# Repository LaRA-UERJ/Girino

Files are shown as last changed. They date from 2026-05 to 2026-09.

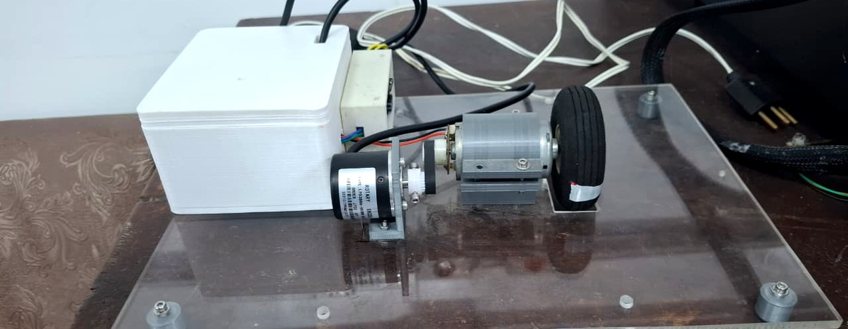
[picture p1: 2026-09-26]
docs/infografico/foto-bancada.jpg

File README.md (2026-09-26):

# Girino





Plataforma didática do **LaRA** (Laboratório de Robótica e Automação) para ensino de controle de motores DC. Integra microcontrolador, driver MOSFET e encoder em uma bancada compacta para introdução prática à leitura de sensores, modulação PWM e controle em malha fechada.

## Status do Projeto

| Componente | Status |
|---|---|
| Estrutura do repositório | ✅ Criada |
| Firmware (ESP8266) | 🚧 Em desenvolvimento |
| Hardware (PCB - KiCad) | 📋 Planejado |
| Mecânico (Caixa 3D) | 📋 Planejado |
| Documentação | 🚧 Em desenvolvimento |
| Exemplos didáticos | 📋 Planejado |

## Funcionalidades

- Controle PWM de motor DC via ESP8266
- Leitura de encoder incremental (LPD3806-600BM — 600 PPR)
- Atualização de firmware via OTA (Wi-Fi)
- Interface web para controle e monitoramento
- Controle PID de velocidade/posição
- Design compacto para bancada de laboratório

## Componentes de Hardware

| Componente | Descrição |
|---|---|
| ESP8266 WROOM | Microcontrolador com Wi-Fi |
| LPD3806-600BM | Encoder incremental, 600 pulsos/revolução |
| Módulo driver motor | Driver genérico MOSFET para motor DC |
| Módulo conversão tensão | Regulador de tensão para alimentação do circuito |

## Estrutura do Repositório

```
Girino/
├── firmware/          # Firmware ESP8266 (PlatformIO)
├── hardware/          # PCB designs (KiCad), gerbers, BOM
├── mechanical/        # Peças 3D (FreeCAD, STL, STEP)
├── docs/              # Documentação completa
├── examples/          # Exemplos didáticos passo a passo
├── gallery/           # Fotos e renders do projeto
└── .github/           # Templates e CI/CD
```

## Início Rápido

Veja o guia completo em [`docs/getting-started.md`](docs/getting-started.md).

### Pré-requisitos

- [PlatformIO](https://platformio.org/) (extensão VSCode recomendada)
- USB cable para gravação inicial do ESP8266
- Componentes listados no BOM (ver [`hardware/bom/`](hardware/bom/))

### Compilar e Gravar

```bash
cd firmware
# Configurar WiFi — copiar template e editar
cp .env.example .env

# Compilar e gravar via USB
pio run -t upload

# Após gravação inicial, usar OTA para atualizações
pio run -t upload --upload-port girino.local
```

## Documentação

- [Guia de Início Rápido](docs/getting-started.md)
- [Montagem do Hardware](docs/hardware-assembly.md)
- [Guia do Firmware](docs/firmware-guide.md)
- [Atualização OTA](docs/ota-update-guide.md)

## Exemplos Didáticos

| # | Exemplo | Descrição |
|---|---|---|
| 01 | [Controle Básico de Motor](examples/01-basic-motor-control/) | PWM para controlar velocidade do motor |
| 02 | [Leitura de Encoder](examples/02-encoder-reading/) | Ler pulsos e calcular velocidade |
| 03 | [Controle PID](examples/03-pid-speed-control/) | Malha fechada de velocidade |
| 04 | [OTA Web Update](examples/04-ota-web-update/) | Atualizar firmware via Wi-Fi |
| 05 | [PID Web Test](examples/05-pid-web-test/) | Teste prático de PID com painel web e gráfico |

## Contribuindo

Contribuições são bem-vindas! Veja o guia em [`CONTRIBUTING.md`](CONTRIBUTING.md).

## Licenças

Este projeto utiliza **tripla licença**:

| Tipo | Licença | Arquivo |
|---|---|---|
| Firmware (código) | **GPL-3.0** | [`LICENSE`](LICENSE) |
| Hardware (PCB, esquemático) | **CERN-OHL-S-2.0** | [`LICENSE`](LICENSE) |
| Documentação e imagens | **CC-BY-SA-4.0** | [`LICENSE`](LICENSE) |

## Equipe

Desenvolvido no **LaRA — Laboratório de Robótica e Automação**.

## Agradecimentos

- Comunidade open-source ESP8266
- [ElegantOTA](https://github.com/ayushsharma82/ElegantOTA)
- [PlatformIO](https://platformio.org/)

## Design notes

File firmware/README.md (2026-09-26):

# Firmware — Girino

Firmware para ESP8266 WROOM com controle PWM de motor DC, leitura de encoder e OTA.

## Requisitos

- [PlatformIO](https://platformio.org/) (CLI ou extensão VSCode)
- Cabo USB para gravação inicial
- Python 3 (para PlatformIO)

## Configuração Inicial

O Girino opera como **Access Point**: ele cria a própria rede Wi-Fi
(chamada `GIRINO_AP` por padrão) e os alunos conectam direto pelo
celular/notebook, sem precisar de roteador nem internet.

```bash
# 1. Copiar template de credenciais
cp .env.example .env

# 2. (Opcional) Ajustar nome e senha da rede criada pelo ESP:
#    WIFI_SSID="GIRINO_AP"
#    WIFI_PASSWORD="girino123"     # mínimo 8 caracteres
#    OTA_PASSWORD="senha_para_ota"
nano .env
```

Após conectar na rede do ESP, acesse `http://192.168.4.1`.

## Compilar e Gravar

### Primeira gravação (via USB)

```bash
# Compilar
pio run

# Compilar e gravar o firmware
pio run -t upload

# Gravar o filesystem (interface web em data/) — OBRIGATÓRIO na
# primeira gravação e sempre que alterar arquivos de data/
pio run -t uploadfs

# Monitor serial (Ctrl+] para sair)
pio device monitor
```

> **Importante:** `pio run -t upload` grava apenas o firmware. A interface
> web (`data/index.html`, `style.css`, `app.js`, `chart.umd.min.js`) vive
> no LittleFS e é gravada com `pio run -t uploadfs`. Se a página abrir com
> "index.html nao encontrado no LittleFS", falta o `uploadfs`.

### Console serial (controle sem Wi-Fi)

O firmware tem um console de comandos na própria porta serial — útil para
bancada, testes rápidos e quando não se quer usar o navegador. Abra o
monitor (`pio device monitor`) e digite `help`:

| Comando | Descrição |
|---|---|
| `help` | lista os comandos |
| `status` | modo, RPM, ângulo, pulsos, heap, IP |
| `enc` | leitura do encoder agora |
| `motor <fwd\|rev\|stop> [0-100]` | comando manual (cancela controladores) |
| `pid <kp> <ki> <kd> <sp>` | configura o PID de velocidade (RPM) |
| `pid start` / `pid stop` | liga/desliga a malha de velocidade |
| `pos <kp> <ki> <kd> <graus>` | configura o PID de posição |
| `pos start` / `pos stop` / `pos zero` | controle de posição / zera origem |
| `autotune <amp> <bias> <n> <sp>` | inicia o relay feedback (velocidade) |
| `autotune pos <amp> <n> <graus>` | inicia o relay feedback (posição, ±amp) |
| `autotune cancel` | cancela o experimento |
| `tune` | mostra Ku/Tu e ganhos ZN/TL/CC do último auto-tune |

Durante qualquer controlador ativo, a telemetria sai a 2 Hz no serial
(`[PID] SP/RPM/Out`, `[Pos] Alvo/Ângulo/Out`, `[AutoTune] RPM/relay`), e o
encoder reporta 1 Hz (`[Encoder] pulsos/p-s/rpm/ângulo`).

### Auto-calibração do sentido (fiação)

No primeiro movimento após o boot, o firmware aplica um pulso curto de
teste e observa a contagem do encoder:

- Contagem positiva → fiação normal (`[Motor] Sentido OK`)
- Contagem negativa → fiação invertida detectada e **corrigida em
  software** (`[Motor] Fiacao invertida detectada`) — não é preciso
  trocar fios: "horário" (FORWARD) sempre aumenta o ângulo medido

As malhas de velocidade e auto-tune usam |RPM| e funcionam com qualquer
polaridade; a calibração garante também o controle de posição.

### Atualizações subsequentes (via OTA)

Conecte o computador na rede do próprio ESP (`GIRINO_AP`) ou use a
interface web em `http://192.168.4.1/update`.

```bash
# Via OTA (computador conectado ao GIRINO_AP)
pio run -t upload --upload-port 192.168.4.1
```

> OTA e `uploadfs` não são a mesma coisa: OTA grava o **firmware**;
> alterações na interface web (pasta `data/`) exigem `pio run -t uploadfs`
> via USB.

## Arquitetura do Firmware

```
src/
├── main.cpp            # Loop principal, WiFi, web server, API REST
├── motor_control.cpp   # Controle PWM do motor
├── encoder.cpp         # Leitura do encoder via interrupção
├── pid.cpp             # Controle PID em malha fechada (50 Hz)
├── pid_autotune.cpp    # Auto-tune via relay feedback (Åström-Hägglund)
└── pid_tuning_rules.cpp # Regras de sintonia Ziegler-Nichols, Tyreus-Luyben e Cohen-Coon

include/
├── pins.h              # Mapeamento de GPIOs (centralizado)
├── config.h            # Constantes e configurações
├── motor_control.h     # Interface do módulo motor
├── encoder.h           # Interface do módulo encoder
├── pid.h               # Interface do módulo PID
├── pid_autotune.h      # Interface do auto-tune
└── pid_tuning_rules.h  # Interface das regras de sintonia
```

## API REST

| Endpoint | Método | Descrição |
|---|---|---|
| `/` | GET | Interface web de controle |
| `/api/motor` | POST | Comando do motor (`direction`, `speed`) |
| `/api/encoder` | GET | Leitura atual do encoder (`pulses`, `rpm`, `angle`) |
| `/api/status` | GET | Status (versão, heap, uptime, IP, clientes do AP, modo) |
| `/api/pid/config` | GET/POST | Configura/consulta ganhos e setpoint do PID de velocidade |
| `/api/pid/start` | POST | Inicia controle de velocidade em malha fechada |
| `/api/pid/stop` | POST | Para o PID, volta a malha aberta |
| `/api/pid/autotune` | GET/POST | Inicia/consulta experimento relay feedback (`plant=speed\|position`) |
| `/api/pid/tuning` | GET | Planta identificada (`plant`), Ku, Tu e sugestões `zn`/`tl`/`cc` |
| `/api/pid/tuning/apply` | POST | Aplica regra de sintonia (`method=ZN|TL|CC`) |
| `/api/pid/response` | GET | Última resposta ao degrau (tempo, setpoint, medida, `unit`) |
| `/api/position/config` | GET/POST | Configura/consulta ganhos e alvo do PID de posição (`target` em graus) |
| `/api/position/start` | POST | Inicia controle de posição (`target` opcional em graus) |
| `/api/position/stop` | POST | Para o controle de posição |
| `/api/position/zero` | POST | Define a posição atual como 0° (origem) |
| `/update` | GET | Interface OTA (ElegantOTA) |

### Exemplos de uso da API

```bash
# Ligar motor em 50% sentido horário (malha aberta)
curl -X POST http://192.168.4.1/api/motor -d "direction=forward&speed=50"

# Parar motor
curl -X POST http://192.168.4.1/api/motor -d "direction=stop&speed=0"

# Ler encoder
curl http://192.168.4.1/api/encoder

# Status do sistema
curl http://192.168.4.1/api/status

# Configurar PID (setpoint em RPM)
curl -X POST http://192.168.4.1/api/pid/config -d "kp=2.0&ki=5.0&kd=0.1&setpoint=100"

# Iniciar malha fechada
curl -X POST http://192.168.4.1/api/pid/start

# Iniciar auto-tune de VELOCIDADE (relay ±10% em torno de bias 90%, 3 ciclos, setpoint 100 RPM)
# O bias (pedestal) precisa vencer a zona morta do motor — o PWM mínimo
# que faz o eixo girar (medido nesta bancada: ~80%). Use `bias` entre esse
# valor e 95%, e `relay_amplitude` de forma que bias ± amplitude fique
# dentro de 0-100%.
curl -X POST http://192.168.4.1/api/pid/autotune -d "plant=speed&relay_amplitude=10&bias=90&cycles=3&setpoint=100"

# Iniciar auto-tune de POSIÇÃO (relé simétrico ±90% em torno do alvo 90°)
# O relé alterna horário/anti-horário; a amplitude precisa ficar acima da
# zona morta (~60%) para ambos os estados moverem o motor. Os ganhos
# resultantes estão em %/° (malha de posição).
curl -X POST http://192.168.4.1/api/pid/autotune -d "plant=position&relay_amplitude=90&cycles=3&target=90"

# Consultar resultado do auto-tune (inclui "plant": onde os ganhos se aplicam)
curl http://192.168.4.1/api/pid/autotune

# Aplicar Tyreus-Luyben
curl -X POST http://192.168.4.1/api/pid/tuning/apply -d "method=TL"

# Baixar resposta ao degrau
curl http://192.168.4.1/api/pid/response

# --- Controle de posição (ângulo) ---

# Zerar a posição atual (define origem 0°)
curl -X POST http://192.168.4.1/api/position/zero

# Configurar PID de posição (alvo 90°)
curl -X POST http://192.168.4.1/api/position/config -d "kp=1.0&ki=0.2&kd=0.05&target=90"

# Iniciar controle de posição
curl -X POST http://192.168.4.1/api/position/start

# Parar controle de posição
curl -X POST http://192.168.4.1/api/position/stop
```

## Pinagem

| GPIO | Pino NodeMCU | Função |
|---|---|---|
| GPIO5 | D1 | Encoder Canal A |
| GPIO4 | D2 | Encoder Canal B |
| GPIO14 | D5 | Motor Direção INB1 (alias IN3) |
| GPIO12 | D6 | Motor Direção INB2 (alias IN4) |
| GPIO13 | D7 | Motor PWM ENB |
| GPIO2 | LED | LED onboard (debug) |

> **Nota sobre o encoder:** o LPD3806 tem saída em coletor aberto — os
> canais A e B exigem resistores de pull-up externos de 4,7k para 3.3V
> (nunca 5V). Ver detalhes em [`docs/hardware-assembly.md`](../docs/hardware-assembly.md).

## Dependências

| Biblioteca | Versão | Descrição |
|---|---|---|
| ElegantOTA | ^3.1.5 | Interface web para atualização OTA |
| ESP8266WebServer | ^1.0 | Servidor HTTP embutido |

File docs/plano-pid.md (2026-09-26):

# Plano — Módulo PID e Auto-Tune

Planejamento do controle PID com auto-tune e comparação de métodos de sintonia para o artigo.

---

## 1. Métodos de Sintonia a Implementar

### Por que comparar métodos?

Todos os trabalhos relacionados usam **um único método** de sintonia, dependendo de MATLAB ou Python. Nenhum oferece comparação visual entre métodos diretamente no hardware. O Girino propõe que o aluno compare ZN, TL e CC no navegador — vendo diferenças de overshoot, tempo de acomodação e erro em regime.

### Métodos selecionados

| # | Método | Tipo | Referência | Por que incluir |
|---|---|---|---|---|
| 1 | **Ziegler-Nichols** | Regra (após relay) | Ziegler & Nichols, 1942 | Mais conhecido. Referência obrigatória em qualquer texto de controle. |
| 2 | **Tyreus-Luyben** | Regra (após relay) | Tyreus & Luyben, 1992 | Mais robusto que ZN, menor overshoot. Bom contraste didático. |
| 3 | **Cohen-Coon** | Regra (após relay) | Cohen & Coon, 1953 | Usado por Alexandre (2025) — permite comparação direta com literatura. |
| 4 | **Relay Feedback** | Auto-tune | Åström & Hägglund, 1984 | Método de identificação. Encontra Ku e Tu automaticamente. **Diferencial do Girino.** |
| 5 | **Manual** | Livre | — | Professor/aluno ajusta Kp, Ki, Kd via web. Maior valor didático. |

### Coeficientes de cada regra (a partir de Ku, Tu)

| Regra | Kp | Ti | Td |
|---|---|---|---|
| **Ziegler-Nichols** | 0.6 × Ku | Tu / 2.0 | Tu / 8.0 |
| **Tyreus-Luyben** | Ku / 2.2 | 2.2 × Tu | Tu / 6.3 |
| **Cohen-Coon** | (Ku/1.35) × (1 + Tu/(4×delay)) | Tu × f(delay) | Tu × g(delay) |

Nota: Cohen-Coon requer estimativa de atraso (dead time) — pode ser obtido via step test.

---

## 2. Fluxo de Auto-Tune (Relay Feedback)

```
Aluno clica "Auto-Tune" na interface web
       ↓
[1] Motor em velocidade nominal (setpoint inicial)
       ↓
[2] ESP8266 aplica relay: +d% se erro > 0, -d% se erro < 0
    (d = amplitude do relay, ex: 20% do PWM)
       ↓
[3] Sistema oscila em limite cycle
    Encoder mede período da oscilação → Tu (período crítico)
    Amplitude do relay × ganho do sensor → Ku (ganho crítico)
       ↓
[4] Calcula Ku e Tu pela média de N ciclos (N=3 a 5)
       ↓
[5] Oferece 3 opções de ganhos: ZN, TL, CC
    Aluno escolhe ou testa todas
       ↓
[6] PID carregado com Kp, Ki, Kd calculados
       ↓
[7] Resposta ao degrau registrada e exibida no gráfico web
       ↓
[8] Aluno pode comparar overshoot, settling time, steady-state error
```

### Parâmetros do Relay Feedback

| Parâmetro | Valor | Observação |
|---|---|---|
| Amplitude do relay (d) | 15–25% PWM | Ajustável. Motor não pode parar. |
| Número de ciclos (N) | 3–5 | Mais ciclos = mais preciso, mais demorado |
| Setpoint nominal | 50% velocidade | Ponto de operação para o experimento |
| Timeout | 30 segundos | Segurança — aborta se não oscilar |

---

## 3. Arquitetura do Firmware

### Novos arquivos

```
firmware/include/
├── pid.h                  → Estrutura PID (Kp, Ki, Kd, setpoint, limites)
├── pid_autotune.h         → Relay feedback (Ku, Tu, estado do experimento)
└── pid_tuning_rules.h     → Calcula Kp/Ki/Kd para ZN, TL, CC

firmware/src/
├── pid.cpp                → Cálculo PID com anti-windup + derivative-on-measurement
├── pid_autotune.cpp       → Máquina de estados do relay feedback
└── pid_tuning_rules.cpp   → Aplica regras de sintonia
```

### PID — Formulacao

```
Implementar forma posicional (standard):

u(t) = Kp × e(t) + Ki × ∫e(τ)dτ + Kd × de(t)/dt

Discreto (T = período de amostragem):

u[k] = Kp × e[k]
     + Ki × T × Σe[j]     (com anti-windup: clamp na integral)
     + Kd × (e[k] - e[k-1]) / T

Ou, para evitar derivative kick:
u[k] = Kp × e[k]
     + Ki × T × Σe[j]
     + Kd × (y[k] - y[k-1]) / T     (derivative on measurement)

Saída u[k] mapeada para PWM: 0 a MOTOR_PWM_RANGE (1023)
```

### Anti-windup

A integral do PID deve ser limitada para evitar saturação:
- Se `u[k] > max_output` → clamp integral em `max_output - Kp×e - Kd×de`
- Se `u[k] < min_output` → clamp integral similarmente

### Sample rate

| Taxa | Observação |
|---|---|
| 50 Hz (20 ms) | Boa para motor DC. ESP8266 aguenta facilmente. |
| 100 Hz (10 ms) | Se encoder de alta velocidade exigir. |
| 10 Hz (100 ms) | Taxa atual do encoder. Pode ser suficiente. |

**Recomendação:** 50 Hz (20ms). Encoder já amostra a 100ms — pode diminuir para 20ms no modo PID.

---

## 4. API REST — Novos Endpoints

| Endpoint | Método | Parâmetros | Descrição |
|---|---|---|---|
| `/api/pid/config` | POST | `kp`, `ki`, `kd`, `setpoint` | Configura ganhos e setpoint do PID |
| `/api/pid/config` | GET | — | Retorna config atual |
| `/api/pid/start` | POST | — | Liga controle em malha fechada |
| `/api/pid/stop` | POST | — | Desliga PID, volta a malha aberta |
| `/api/pid/autotune` | POST | `relay_amplitude`, `cycles` | Inicia experimento relay feedback |
| `/api/pid/autotune` | GET | — | Status do auto-tune (running/done/results) |
| `/api/pid/tuning` | GET | — | Retorna Ku, Tu + sugestões ZN/TL/CC |
| `/api/pid/tuning/apply` | POST | `method` (ZN/TL/CC) | Aplica regra de sintonia escolhida |
| `/api/pid/response` | GET | — | Última resposta ao degrau (array tempo, setpoint, velocidade) |

### Exemplo de uso

```bash
# 1. Iniciar auto-tune
curl -X POST http://192.168.1.100/api/pid/autotune \
  -d "relay_amplitude=20&cycles=3"

# 2. Ver resultados
curl http://192.168.1.100/api/pid/autotune
# → {"status":"done","ku":5.2,"tu":0.35}

# 3. Ver sugestões
curl http://192.168.1.100/api/pid/tuning
# → {"ku":5.2,"tu":0.35,
#     "ZN":{"kp":3.12,"ki":17.83,"kd":0.14},
#     "TL":{"kp":2.36,"ki":4.55,"kd":0.06},
#     "CC":{"kp":3.85,"ki":15.20,"kd":0.12}}

# 4. Aplicar Tyreus-Luyben
curl -X POST http://192.168.1.100/api/pid/tuning/apply \
  -d "method=TL"

# 5. Iniciar malha fechada
curl -X POST http://192.168.1.100/api/pid/start \
  -d "setpoint=50"

# 6. Coletar resposta ao degrau
curl http://192.168.1.100/api/pid/response
# → {"data":[[0,0],[0.02,5],...,[3.0,49.8]],"setpoint":50}
```

---

## 5. Interface Web — Componentes Novos

### Painel de PID (adicionar à página principal)

```
┌─────────────────────────────────────┐
│  Controle PID                       │
│                                     │
│  Setpoint: [____] RPM               │
│  Kp: [____]  Ki: [____]  Kd: [____] │
│                                     │
│  [▶ Iniciar PID]  [⏹ Parar]         │
│  [🔧 Auto-Tune]  [📊 Step Response] │
│                                     │
│  Método de sintonia:                │
│  ○ Ziegler-Nichols                  │
│  ○ Tyreus-Luyben (recomendado)      │
│  ○ Cohen-Coon                       │
│  ○ Manual                           │
│                                     │
│  ┌─────────────────────────────┐    │
│  │  Gráfico: Tempo vs RPM      │    │
│  │  (setpoint + resposta real)  │    │
│  │  ~~~~~~~~~~~~~~~~~~~~~~~~    │    │
│  └─────────────────────────────┘    │
│                                     │
│  Resultados Auto-Tune:              │
│  Ku = 5.2  Tu = 0.35s              │
│  Overshoot: 12%  Settling: 1.8s     │
└─────────────────────────────────────┘
```

### Biblioteca de gráficos

Usar **Chart.js** (CDN, leve, sem instalação):
- Gráfico de linha em tempo real
- Eixo X: tempo (s), Eixo Y: RPM
- Linha tracejada: setpoint
- Linha sólida: velocidade real
- Exportar dados como CSV

---

## 6. Estrutura Didática (Exemplos Progressivos)

| # | Exemplo | Conceito | Atividade do Aluno |
|---|---|---|---|
| 01 | Controle básico de motor | PWM, duty cycle | Variar PWM e observar velocidade |
| 02 | Leitura de encoder | Interrupção, quadratura | Contar pulsos, calcular RPM |
| 03 | Curva do motor (malha aberta) | Modelagem empírica | Aplicar PWM de 0 a 100%, plotar curva RPM vs PWM |
| 04 | PID manual | Controle em malha fechada | Ajustar Kp, Ki, Kd e observar resposta |
| 05 | Auto-tune | Identificação de sistemas | Executar relay feedback, obter Ku e Tu |
| 06 | Comparação de métodos | ZN vs TL vs CC | Aplicar cada método, comparar gráficos |

### Valor didático da comparação de métodos

O aluno aprende que:
- ZN tem resposta rápida mas muito overshoot
- TL é mais lento mas sem oscilação
- CC é intermediário
- Manual pode ser melhor se o aluno entende o sistema
- Não existe "melhor método" — depende do critério (velocidade, robustez, etc.)

---

## 7. Comparação com Trabalhos Existentes

| Aspecto | Alexandre 2025 | Cabral 2025 | MotoShield | OpenMCT | **Girino** |
|---|---|---|---|---|---|
| Método de sintonia | Cohen-Coon | z-domain (MATLAB) | MATLAB sysID | Coeficientes GUI | **Auto-tune + 3 regras + manual** |
| Auto-tune embarcado | ❌ | ❌ | ❌ | ❌ | **✅ (Relay Feedback)** |
| Comparação de métodos | ❌ | ❌ | ❌ | ❌ | **✅ (ZN vs TL vs CC)** |
| Visualização | SCADA externo | MATLAB | MATLAB | Python/Qt | **Navegador web** |
| Software necessário | SCADA | MATLAB | MATLAB | Python+Qt | **Nenhum** |

### Argumento para o paper

> "Enquanto plataformas existentes usam um único método de sintonia dependente de software externo (MATLAB, Python), o Girino implementa auto-tune embarcado via relay feedback (Åström-Hägglund) e permite comparação direta de três regras clássicas (Ziegler-Nichols, Tyreus-Luyben, Cohen-Coon) através de interface web — sem instalação de qualquer software."

---

## 8. Pendências para o Artigo (Checklist)

- [x] Levantamento bibliográfico (~70 referências)
- [x] Análise comparativa dos trabalhos relacionados
- [x] Planejamento dos métodos de sintonia
- [x] Implementar PID no firmware (pid.h + pid.cpp)
- [x] Implementar auto-tune (pid_autotune.h + pid_autotune.cpp)
- [x] Implementar regras de sintonia (ZN, TL, CC)
- [x] Adicionar endpoints API REST para PID
- [ ] Interface web com gráfico de resposta ao degrau (UI pronta; validar com hardware real)
- [ ] Modelagem matemática do sistema motor+encoder
- [ ] Testes experimentais: comparar ZN vs TL vs CC
- [ ] Avaliação pedagógica com alunos
- [ ] Redação do artigo

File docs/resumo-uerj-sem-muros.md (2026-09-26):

# Girino: plataforma didática de baixo custo para ensino de controle de motores DC via navegador

**Autor:** Ítalo Rosa Gonçalves
**Orientador:** Prof. Ângelo Mondaini Calvão
**Laboratório:** LaRA — Laboratório de Robótica e Automação (UERJ)
**Modalidade:** Estágio Interno Complementar
**ODS:** 4 — Educação de Qualidade

## Resumo

O ensino de controle exige prática experimental, mas bancadas comerciais são caras e as alternativas de baixo custo dependem de software proprietário ou instalações locais, restringindo o acesso dos estudantes. Alinhado ao ODS 4 (Educação de Qualidade), este trabalho desenvolve o Girino, plataforma didática de baixo custo para controle de motores DC, acessível apenas pelo navegador.

A bancada reúne microcontrolador com Wi-Fi, encoder de realimentação e driver de potência. O firmware implementa controle de velocidade e de posição em malha fechada, com auto-sintonia e comparação de métodos de sintonia. A interface web embarcada permite operar o motor e acompanhar a resposta em qualquer dispositivo, sem instalar nada, e o firmware é atualizado por OTA. O hardware também foi projetado no laboratório.

A bancada foi montada e validada: os controles de velocidade e posição operam em malha fechada, a auto-sintonia identifica o sistema e sugere ganhos, e a interface funciona sem internet. A caracterização do motor e a calibração da fiação também foram tratadas.

O Girino se mostra uma plataforma funcional e acessível, que dispensa MATLAB, Python ou qualquer instalação e facilita a manutenção das bancadas via OTA. Como continuidade, prevê-se a modelagem do sistema, a comparação experimental dos métodos e a avaliação pedagógica com alunos.

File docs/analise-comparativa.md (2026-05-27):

# Análise Comparativa — Girino vs Trabalhos Relacionados

Review sistemático dos trabalhos mais próximos do Girino, com análise de lacunas e diferenciais.

---

## 1. Análise dos Trabalhos Mais Próximos

### 1.1 Mini bancada de baixo custo com motores CC e encoder (Cabral et al., 2025)

**Veículo:** Ciência e Natura (UFSM), Vol. 47, No. esp. 4
**DOI:** https://doi.org/10.5902/2179460X92211

**Descrição:** Bancada didática de baixo custo com motor DC e encoder para ensino de controle realimentado em engenharia. Inclui modelagem matemática do motor, derivação da função de transferência e projeto de controlador digital discreto para controle de velocidade angular. Validação via MATLAB/Simulink.

| Aspecto | Cabral et al. (2025) | Girino |
|---|---|---|
| Microcontrolador | Arduino | ESP8266 WROOM |
| Motor | DC com encoder | DC com encoder (LPD3806-600BM) |
| Encoder | Sim | Sim (600 PPR) |
| PID | Sim (discreto) | Planejado |
| Interface | MATLAB/Simulink | **Web embarcada (navegador)** |
| Wi-Fi | Não | **Sim** |
| OTA | Não | **Sim (ElegantOTA)** |
| Modelagem matemática | **Sim (completa)** | A fazer |
| Custo | Baixo | Baixo |
| Open-source | Parcial | **Sim (tripla licença)** |

**Pontos fortes:** Modelagem matemática rigorosa, validação MATLAB/Simulink, aplicação em engenharia.
**Lacunas:** Sem conectividade, depende de MATLAB (software proprietário e caro), sem OTA.

---

### 1.2 Análise do controle PID aplicado no controle de velocidade de um motor CC (Alexandre et al., 2025)

**Veículo:** Revista de Engenharia e Tecnologia (UEPG), Vol. 17, No. 1
**URL:** https://revistas.uepg.br/index.php/ret/article/view/24725

**Descrição:** Controle PID de velocidade de motor DC usando Arduino UNO R3, encoder rotativo e ponte H L298N. Sintonia via método Cohen-Coon. Aplicação SCADA para monitoramento. Testes em 200, 275 e 120 RPM com erro em regime permanente próximo de zero.

| Aspecto | Alexandre et al. (2025) | Girino |
|---|---|---|
| Microcontrolador | Arduino UNO R3 | ESP8266 WROOM |
| Motor | DC | DC |
| Encoder | Rotativo | LPD3806-600BM |
| Driver | L298N (ponte H) | MOSFET genérico |
| PID | Sim (Cohen-Coon) | Planejado |
| Interface | SCADA desktop | **Web embarcada** |
| Wi-Fi | Não | **Sim** |
| OTA | Não | **Sim** |
| Monitoramento | Aplicativo dedicado | **Navegador web** |
| Sintonia | Cohen-Coon | A definir |

**Pontos fortes:** Hardware quase idêntico ao Girino, resultados experimentais validados, método de sintonia definido.
**Lacunas:** Sem Wi-Fi, sem web, sem OTA, aplicativo SCADA requer instalação.

---

### 1.3 Bancada Didática para Controle de Velocidade de Motor CC (Segundo et al., 2019)

**Veículo:** SBAI — Simpósio Brasileiro de Automação Inteligente
**URL:** https://proceedings.science/sbai-2019/trabalhos/desenvolvimento-de-uma-bancada-didatica-para-praticas-de-controle-de-velocidade

**Descrição:** Bancada didática com Arduino + interface gráfica MATLAB para controle de velocidade de motor CC. Apresenta fabricação, arranjo do motor, circuitos de potência e controle.

| Aspecto | Segundo et al. (2019) | Girino |
|---|---|---|
| Microcontrolador | Arduino | ESP8266 WROOM |
| Interface | MATLAB GUI | **Web embarcada** |
| Conectividade | USB | **Wi-Fi + OTA** |
| Contexto | Graduação em engenharia | Graduação em engenharia |

**Pontos fortes:** Publicado em congresso SBA (relevante), demonstração prática completa.
**Lacunas:** Dependência MATLAB, sem conectividade sem fio.

---

### 1.4 MotoShield (Takács et al., 2021)

**Veículo:** IEEE EDUCON
**DOI:** https://ieeexplore.ieee.org/document/9453979

**Descrição:** Shield Arduino miniaturizado com motor DC + encoder incremental. Open-source com biblioteca para IDE Arduino. Exemplos de controle PID. Design compacto para "pocket labs".

| Aspecto | MotoShield | Girino |
|---|---|---|
| Forma | Shield Arduino R3 | PCB independente |
| MCU | Arduino UNO/Mega | ESP8266 WROOM |
| Conectividade | Nenhuma | **Wi-Fi** |
| Interface | Arduino IDE serial | **Web embarcada** |
| OTA | Não | **Sim** |
| API | C/C++ library | **REST (HTTP)** |
| Citação | 8 citações | — |

**Pontos fortes:** Projeto maduro, hardware integrado, publicado em IEEE, comunidade ativa.
**Lacunas:** Sem conectividade, sem interface web, sem OTA.

---

### 1.5 OpenMCT (Von Chong, 2026)

**Veículo:** HardwareX (Elsevier)
**DOI:** https://www.sciencedirect.com/science/article/pii/S2468067226000544

**Descrição:** Kit educacional open-source para controle de motor DC. Teensy 4 + encoder incremental + H-bridge + sensor de corrente. GUI Python/Qt com telemetria, logging, sintonia PID e controle no domínio z. Certificado OSHWA.

| Aspecto | OpenMCT | Girino |
|---|---|---|
| MCU | Teensy 4.x | ESP8266 WROOM |
| Encoder | Incremental | LPD3806-600BM |
| GUI | Python/Qt (desktop) | **Web (navegador)** |
| Conectividade | USB | **Wi-Fi** |
| OTA | Não | **Sim** |
| Certificação | OSHWA | Planejado |
| Maturidade | Alta (2026) | Inicial |
| Software necessário | Python + Qt | **Nenhum** |

**Pontos fortes:** Projeto mais maduro e completo, certificado OSHWA, GUI rica, controle no domínio z.
**Lacunas:** Requer instalação de Python + Qt, sem Wi-Fi, sem OTA, sem web.

---

### 1.6 Reck & Sreenivas (2015, 2016) — Papers Fundacionais

**Veículos:** ACC (IEEE), Electronics (MDPI)
**DOI:** https://ieeexplore.ieee.org/document/7171014 e https://www.mdpi.com/2079-9292/5/3/43

**Descrição:** Kit portátil "take-home" com motor DC + caixa de redução + encoder. Compara Arduino, Raspberry Pi e DAQ comercial. Demonstração de controle PID de posição. 97 citações combinadas.

| Aspecto | Reck & Sreenivas | Girino |
|---|---|---|
| MCU | Arduino / RPi | ESP8266 |
| Motor | DC + gearbox | DC |
| Encoder | Sim | Sim |
| PID | Posição e velocidade | Velocidade (planejado) |
| Conectividade | USB / Ethernet | **Wi-Fi nativo** |
| Portabilidade | Kit take-home | **Kit take-home + web** |
| Avaliação pedagógica | **Sim (completa)** | A fazer |

**Pontos fortes:** Papers fundacionais do campo, avaliação pedagógica formal com estudantes, custo detalhado.
**Lacunas:** Sem Wi-Fi nativo, sem web embarcada, sem OTA.

---

### 1.7 TCLab — Temperature Control Lab (Hedengren et al., 2020+)

**Veículo:** Multiple (19+ papers)
**URL:** https://apmonitor.com/pdc/index.php/Main/ArduinoTemperatureControl

**Descrição:** Laboratório de controle de temperatura em Arduino Leonardo. Dois aquecedores, dois sensores. Suporte Python/MATLAB/Simulink. Adotado mundialmente. Modelo de sucesso em publicação de plataforma educacional.

| Aspecto | TCLab | Girino |
|---|---|---|
| Variável controlada | Temperatura | Velocidade/posição angular |
| MCU | Arduino Leonardo | ESP8266 |
| Software | Python/MATLAB | **Nenhum (navegador)** |
| Conectividade | USB | **Wi-Fi** |
| Publicações | **19+ papers** | 0 |
| Adoção | Mundial | — |

**Pontos fortes:** Modelo de sucesso em publicação, comunidade grande, materiais didáticos completos.
**Lacunas:** Variável diferente (temperatura vs motor), sem Wi-Fi, requer Python ou MATLAB.

**Nota:** O TCLab é o **modelo a seguir** para estratégia de publicação — mostrar como uma plataforma open-source pode gerar dezenas de papers e ser adotada globalmente.

---

## 2. Tabela Comparativa Geral

| Característica | Cabral 2025 | Alexandre 2025 | Segundo 2019 | MotoShield 2021 | OpenMCT 2026 | Reck 2015 | TCLab 2020 | **Girino** |
|---|---|---|---|---|---|---|---|---|
| Motor DC | ✅ | ✅ | ✅ | ✅ | ✅ | ✅ | — | **✅** |
| Encoder | ✅ | ✅ | — | ✅ | ✅ | ✅ | — | **✅** |
| PID | ✅ | ✅ | ✅ | ✅ | ✅ | ✅ | ✅ | **Planejado** |
| Microcontrolador | Arduino | Arduino | Arduino | Arduino | Teensy 4 | Arduino/RPi | Arduino Leo | **ESP8266** |
| Wi-Fi nativo | ❌ | ❌ | ❌ | ❌ | ❌ | ❌ | ❌ | **✅** |
| Interface web | ❌ | ❌ | ❌ | ❌ | ❌ | ❌ | ❌ | **✅** |
| API REST | ❌ | ❌ | ❌ | ❌ | ❌ | ❌ | ❌ | **✅** |
| OTA firmware | ❌ | ❌ | ❌ | ❌ | ❌ | ❌ | ❌ | **✅** |
| Sem software externo | ❌ | ❌ | ❌ | ❌ | ❌ | ❌ | ❌ | **✅** |
| Open-source HW | Parcial | ❌ | ❌ | ✅ | ✅ | ✅ | ✅ | **✅** |
| Modelagem matemática | ✅ | — | — | — | ✅ | ✅ | ✅ | **A fazer** |
| Avaliação com alunos | — | — | — | — | — | ✅ | ✅ | **A fazer** |
| Custo (< US$ 20) | ✅ | ✅ | ✅ | — | — | ❌ | ✅ | **✅** |
| Contexto brasileiro | ✅ | ✅ | ✅ | ❌ | ❌ | ❌ | ❌ | **✅** |

---

## 3. Análise de Lacunas (Gap Analysis)

### O que todos os trabalhos têm em comum:
1. Motor DC + encoder como planta
2. Microcontrolador como controlador
3. Foco em ensino de controle
4. Baixo custo

### O que nenhum trabalho oferece:
1. **Conectividade Wi-Fi nativa** — Todos usam Arduino UNO/Mega/Teensy sem Wi-Fi
2. **Interface web embarcada** — Todos dependem de MATLAB, Python, LabVIEW ou aplicativo desktop
3. **OTA firmware updates** — Nenhum permite atualizar o firmware sem fio
4. **API REST** — Nenhum oferece interface HTTP para integração
5. **Zero instalação de software** — Todos exigem que o aluno instale algo

### O que o Girino ainda precisa desenvolver:
1. **Modelagem matemática** do sistema motor + encoder
2. **Implementação do PID** com sintonia
3. **Avaliação pedagógica** com alunos
4. **Comparação experimental** simulação vs hardware

---

## 4. Diferenciais do Girino para o Artigo

### Argumento Central

> As plataformas existentes para ensino de controle com motor DC compartilham uma limitação fundamental: **a dependência de software proprietário (MATLAB) ou instalação local (Python, LabVIEW)** para interação com o hardware. Isso cria barreiras de acessibilidade, especialmente em contextos onde alunos não têm acesso a licenças acadêmicas ou computadores pessoais.
>
> O Girino propõe uma mudança de paradigma: **o navegador web como interface universal**. Com ESP8266 e servidor web embarcado, o aluno interage com o motor via qualquer dispositivo com navegador — celular, tablet, Chromebook — sem instalar nada. A atualização OTA permite que o professor atualize o firmware de todas as bancadas remotamente.

### Contribuições Específicas

| # | Contribuição | Novidade |
|---|---|---|
| 1 | ESP8266 como plataforma para ensino de controle | Primeiro uso documentado no contexto |
| 2 | Interface web embarcada para controle de motor | Nenhum trabalho anterior oferece |
| 3 | API REST para experimentação de controle | Abre possibilidades de automação e integração |
| 4 | OTA para gestão de bancadas de laboratório | Facilita manutenção em escala |
| 5 | Zero instalação de software | Democratiza o acesso ao laboratório |
| 6 | Licença tripla open-source | Garante reprodutibilidade e colaboração |

---

## 5. Referências da RBEF e Periódicos Brasileiros

### Papers na RBEF com uso de microcontroladores (contexto de apoio)

| # | Título | Autores | Ano | DOI | Relevância |
|---|---|---|-----|-----|---|
| 1 | Determinación del rendimiento de un motor de Stirling usando Arduino | Savall-Alemany et al. | 2020 | https://doi.org/10.1590/1806-9126-RBEF-2020-0279 | Arduino + sensores em motor. Mostra abordagem de baixo custo. |
| 2 | Potência e força eletromotriz em um gerador didático de corrente alternada | Alves et al. | 2022 | https://doi.org/10.1590/1806-9126-RBEF-2021-0379 | Motor com controle de rotação. Medição de EMF. |
| 3 | Uma aula sobre conversão de energia utilizando bicicleta, motor, alternador e lâmpada | Borges, Dickman, Vertchenko | 2018 | https://doi.org/10.1590/1806-9126-RBEF-2017-0215 | Motor em experimento didático de física. |
| 4 | Motor elétrico — SimuFísica® | Souza, Oliveira, Luiz | 2024 | https://doi.org/10.1590/1806-9126-RBEF-2023-0219 | Simulador de motor para ensino. Equações e dinâmica. |
| 5 | Sistema automatizado para medición del coeficiente de fricción estática | González-Laprea, Santiago | 2021 | https://doi.org/10.1590/1806-9126-RBEF-2021-0056 | Arduino + motor + sensores para ensino de física. |
| 6 | A placa Arduino: uma opção de baixo custo para experiências de física | Souza et al. | 2011 | https://doi.org/10.1590/S1806-11172011000100026 | Paper fundacional Arduino na RBEF. |
| 7 | Física com Arduino para iniciantes | Cavalcante et al. | 2011 | https://doi.org/10.1590/S1806-11172011000400018 | Arduino para automação e aquisição de dados. |
| 8 | Strain and deformation measurement using Arduino | Silva et al. | 2019 | https://doi.org/10.1590/1806-9126-RBEF-2018-0206 | Aquisição com Arduino e condicionamento de sinal. |
| 9 | Kit experimental com Arduino para ensino de Física Moderna | Silveira, Girardi | 2017 | https://doi.org/10.1590/1806-9126-RBEF-2016-0287 | Kit de baixo custo com interface web. |
| 10 | Física experimental com Arduino: ondas em uma corda | Sousa Jr. et al. | 2020 | https://doi.org/10.1590/1806-9126-RBEF-2020-0177 | Técnicas de otimização de ADC e timing. |
| 11 | Kit experimental com Arduino para oscilações em tempo real | Matos Pereira, da Silva | 2021 | https://doi.org/10.1590/1806-9126-RBEF-2021-0186 | Aquisição e visualização em tempo real. |
| 12 | Práticas experimentais de Física a distância: Millikan com Arduino | Barros, Dias | 2019 | https://doi.org/10.1590/1806-9126-RBEF-2019-0049 | **Controle remoto de experimento via web.** Filosofia similar ao Girino. |
| 13 | Sismógrafo empregando sensores piezoelétricos em Arduino | Amorim et al. | 2021 | https://doi.org/10.1590/1806-9126-RBEF-2021-0267 | Aquisição de dados com Arduino. |

### Revisões sistemáticas brasileiras sobre Arduino no ensino

| # | Título | Autores | Ano | URL |
|---|---|---|-----|-----|
| 14 | Contribuições do Arduino no Ensino de Física: revisão sistemática | — | ~2018 | https://bia.ifpi.edu.br/jspui/handle/123456789/4839 |
| 15 | Arduino no Ensino de Física: Revisão Sistemática de Literatura | UFPA | ~2022 | https://www.periodicos.ufpa.br/index.php/revistaamazonia/article/view/12175 |

---

## 6. Estratégia de Publicação Recomendada

### Opção A: RBEF (Revista Brasileira de Ensino de Física)
- **Vantagem:** Lacuna clara — nenhum paper sobre motor + encoder + controle. Público amplo de físicos educadores.
- **Desafio:** Precisa de enfoque em física (não apenas engenharia). Argumentar que controle é relevante para física moderna.
- **Ângulo:** "Plataforma de baixo custo para ensino de controle e automação via navegador web"

### Opção B: COBENGE (Congresso Brasileiro de Educação em Engenharia)
- **Vantagem:** Foco direto em educação em engenharia. Edição 2026 em Belo Horizonte.
- **Desafio:** Congresso (não periódico). Pode ser stepping stone para artigo em periódico.

### Opção C: CBA (Congresso Brasileiro de Automática)
- **Vantagem:** Já publicou trabalhos similares (Sousa 2022, Alves 2024). Comunidade de controle.
- **Desafio:** Público técnico, precisa de modelagem matemática e resultados experimentais.

### Opção D: RBEE (Revista Brasileira de Educação em Engenharia)
- **Vantagem:** Periódico direto de ABENGE. Foco em educação.
- **Recomendação:** Ideal para artigo completo com avaliação pedagógica.

### Estratégia sugerida:
1. **Curto prazo:** Submeter ao COBENGE 2026 ou CBA (paper de 6-8 páginas)
2. **Médio prazo:** Submeter artigo completo à RBEF ou RBEE com avaliação pedagógica
3. **Longo prazo:** Submeter versão estendida ao IEEE EDUCON ou HardwareX

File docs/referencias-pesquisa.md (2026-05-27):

# Referências de Pesquisa — Girino

Levantamento bibliográfico para fundamentação do artigo sobre a plataforma Girino.
Organizado por relevância para o projeto.

---

## 1. Trabalhos Diretamente Relacionados

Plataformas de baixo custo com motor DC + encoder + microcontrolador para ensino de controle.

| # | Título | Autores | Ano | Veículo | URL | Descrição |
|---|---|---|-----|---|-----|---|
| 1 | Low-cost DC motor system for teaching automatic controls | Cook, Bonniwell, Rodriguez et al. | 2020 | ACC (IEEE) | https://ieeexplore.ieee.org/document/9147593 | Arduino Mega 2560 como DAQ com encoder para ensino de PID de posição e velocidade. Arquitetura diretamente comparável ao Girino. |
| 2 | A low-cost feedback control systems laboratory setup via Arduino–Simulink interface | Uyanik, Catalbas | 2018 | Computer Applications in Engineering Education (Wiley) | https://onlinelibrary.wiley.com/doi/abs/10.1002/cae.21989 | Arduino Uno + driver shield + motor DC com encoder. Modelagem e PID via MATLAB/Simulink. ~50 citações. |
| 3 | Developing a new affordable DC motor laboratory kit for an existing undergraduate controls course | Reck, Sreenivas | 2015 | ACC (IEEE) | https://ieeexplore.ieee.org/document/7171014 | Paper fundacional. Kit com motor DC + caixa de redução + encoder. Compara Arduino vs Raspberry Pi vs DAQ comercial. 47 citações. |
| 4 | Developing an affordable and portable control systems laboratory kit with a Raspberry Pi | Reck, Sreenivas | 2016 | Electronics (MDPI), 5(3), 43 | https://www.mdpi.com/2079-9292/5/3/43 | Continuação do paper anterior. Kit portátil com Raspberry Pi. Discussão de custo e feedback de alunos. 50 citações. |
| 5 | Evaluating the Effectiveness of an Affordable and Portable Laboratory Kit for an Introductory Control Systems Course | Reck, Sreenivas, Loui | 2019 | Advances in Engineering Education (AEE) | https://eric.ed.gov/?id=EJ1234567 | Avaliação pedagógica mostrando ganhos mensuráveis de aprendizagem. Útil para justificar o valor didático do Girino. |
| 6 | Does inexpensive hardware obfuscate simple experiments for control systems laboratories? | Schinstock, Smith, White | 2017 | ACC (IEEE) | https://ieeexplore.ieee.org/document/7963543 | Análise crítica da adequação de hardware de baixo custo para labs de controle. Contra-argumento importante. |
| 7 | Low-cost DC motor control system experiments for engineering students | Bhatta, Salim, Borra, Li | 2023 | ASEE Annual Conference | https://peer.asee.org/ | Experimentos open-source de motor DC para currículo de sistemas de controle. |
| 8 | PID control of a DC motor using LabVIEW Interface for Embedded Platforms | Găşpăresc | 2016 | IEEE SACI | https://ieeexplore.ieee.org/document/7507397 | Arduino Uno para PID de baixo custo. Velocidade via encoder óptico. Análogo ao Girino. |
| 9 | Development of DC motor speed control using PID based on Arduino and MATLAB for laboratory trainer | Supriyono, Alanro, Supardi | 2024 | Jurnal Nasional Teknik Elektro | https://jnte.ft.unand.ac.id/ | Trainer para laboratório com Arduino + MATLAB. Canais A/B do encoder conectados aos pinos. |
| 10 | A Cost-Effective LabVIEW-Arduino Framework for Control System Education | Gadia, Marcos | 2025 | IJIET | https://www.ijiet.org/vol15/IJIET-V15N8-2360.pdf | Framework LabVIEW-Arduino para ensino de controle PID. Escalável para aprendizado remoto. |

---

## 2. Plataformas Open-Source para Ensino de Controle

Projetos open-source com filosofia similar ao Girino.

| # | Título / Plataforma | Autores | Ano | Veículo | URL | Descrição |
|---|---|---|-----|---|-----|---|
| 11 | AutomationShield: An open-source hardware and software initiative for control engineering education | Takács, Mikuláš, Gulan et al. | 2023 | IFAC-PapersOnLine | https://www.sciencedirect.com/science/article/pii/S2405896323006146 | Ecossistema de shields Arduino para educação em controle (motor, térmico, levitação magnética). API em C/C++, MATLAB e Simulink. 29 citações. |
| 12 | MotoShield: Open miniaturized DC motor hardware prototype for control education | Takács, Boldocký, Mikuláš et al. | 2021 | IEEE EDUCON | https://ieeexplore.ieee.org/document/9453979 | **O projeto mais similar ao Girino.** Shield Arduino com motor DC + encoder incremental. Open-source com exemplos de PID. |
| 13 | OpenMCT: An Open-Source DC Motor Control Educational Kit | Von Chong | 2026 | HardwareX (Elsevier) | https://www.sciencedirect.com/science/article/pii/S2468067226000544 | Kit recente (2026). Teensy 4 + encoder + H-bridge + GUI Python/Qt. Certificado OSHWA. |
| 14 | OptoShield: A low-cost tool for control and mechatronics education | Takács, Konkoly, Gulan | 2019 | Asian Control Conference (ASCC, IEEE) | https://ieeexplore.ieee.org/document/8823714 | Parte da família AutomationShield. Baseado no Arduino Motor Shield. |
| 15 | Controlly: Open Source Platform for Learning and Teaching Control Systems | — | 2016 | IEEE IES | https://ieeexplore.ieee.org/document/7345194 | Plataforma visual (Google Blockly) para ensino de controle SISO/MIMO. Root locus, Ziegler-Nichols, Cohen-Coon. |
| 16 | RaspyControl Lab: A fully open-source and real-time remote laboratory for education in automatic control systems | Ariza, Galvis | 2023 | HardwareX | https://www.sciencedirect.com/science/article/pii/S2468067223000280 | Lab remoto open-source com Raspberry Pi + Python. 33 citações. |
| 17 | TCLab — Temperature Control Lab | Hedengren et al. (BYU) | 2020+ | Multiple venues | https://apmonitor.com/pdc/index.php/Main/ArduinoTemperatureControl | Lab de temperatura em Arduino Leonardo com Python/MATLAB/Simulink. 19+ papers associados. Adotado mundialmente. Referência para o modelo de publicação. |

### Repositórios GitHub

| Plataforma | URL |
|---|---|
| OpenMCT | https://github.com/AlejoBSmith/DC_Motor |
| AutomationShield | https://github.com/automationshield/automationshield |
| TCLab (Arduino) | https://github.com/APMonitor/arduino |
| Interactive PID Controller | https://github.com/Atrabilis/Interactive_PID_Controller |
| DCMotorControl (ROS2 + ESP32) | https://github.com/HumbertoBM2/DCMotorControl |

---

## 3. Publicações Brasileiras

Trabalhos em veículos brasileiros sobre plataformas didáticas de controle.

### 3.1 CBA — Congresso Brasileiro de Automática (SBA)

| # | Título | Autores | Ano | URL | Descrição |
|---|---|---|-----|-----|---|
| 18 | Módulo didático para acionamento e controle de velocidade de um motor CC para práticas interdisciplinares em cursos de engenharias | Sousa, Nunes, Silva et al. | 2022 | https://sba.org.br/ | **Diretamente relevante.** Módulo didático para controle de velocidade de motor CC. Publicado no principal congresso brasileiro de automática. |
| 19 | Bancada Didática de Baixo Custo para Ensino de Identificação de Sistemas e Projeto de Controle de Temperatura | Nascimento, Moura, Santana | 2024 | https://sba.org.br/ | Bancada de baixo custo para identificação de sistemas e projeto de controle. |
| 20 | Plataforma Didática para Controle de Vazão e Nível a Partir de Resíduos Eletroeletrônicos | Júnior, Leite, Netto et al. | 2022 | https://sba.org.br/ | Plataforma de baixo custo construída com resíduos eletrônicos. |
| 21 | Modicon: Módulos para ensino de identificação e controle de processos | Carmo, Araújo et al. | 2020 | https://sba.org.br/ | Plataforma modular para ensino de identificação e controle. Inclui feedback de alunos. |
| 22 | Sistema Embarcado para Aplicações em Disciplinas Experimentais | Duarte, Junior, Oliveira et al. | 2024 | https://sba.org.br/ | ESP32 com MCPWM para controle de motor via PWM. Arquitetura próxima ao Girino. |
| 23 | Experimental Teaching Platform: A Solution Through IoT Approach | Alves, Santos, Júnior et al. | 2024 | https://sba.org.br/ | Plataforma experimental IoT para disciplinas de controle. **Muito relevante para a capacidade Wi-Fi do Girino.** |
| 24 | Plataforma experimental de eletricidade básica com acesso e controle remotos implementada diretamente em microcontrolador | Oliveira, Morais | 2022 | https://sba.org.br/ | Plataforma com acesso remoto via microcontrolador conectado à internet. |
| 25 | Exploring the Pedagogical Potential of ESP32 as a Teaching Tool for IoT in Residential Automation Educational Workshop | Lisboa, Silva et al. | 2024 | https://sba.org.br/ | ESP32 como ferramenta de ensino de baixo custo para automação. |
| 26 | Construção de uma planta de nível monotanque, de baixo custo, para estudo de modelagem e controle de processos | Carmo, Araújo et al. | 2022 | https://sba.org.br/ | Planta de baixo custo para modelagem e controle. |

### 3.2 SBAI — Simpósio Brasileiro de Automação Inteligente

| # | Título | Autores | Ano | URL | Descrição |
|---|---|---|-----|-----|---|
| 27 | Desenvolvimento de uma Bancada Didática para Práticas de Controle de Velocidade de Motor de Corrente Contínua | Segundo et al. | 2019 | https://proceedings.science/sbai-2019/trabalhos/desenvolvimento-de-uma-bancada-didatica-para-praticas-de-controle-de-velocidade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 | Bancada didática com Arduino + interface MATLAB para controle de velocidade de motor CC. |
| 28 | Uso de documentos interativos no Matlab para o ensino de sistemas de controle | Munaro, Rosado Filho | 2023 | https://sba.org.br/ | Documentos MATLAB interativos para ensino de controle. Análise de resposta de motor. |

### 3.3 Outros Veículos Brasileiros

| # | Título | Autores | Ano | Veículo | URL | Descrição |
|---|---|---|-----|---|-----|---|
| 29 | Mini bancada de baixo custo com motores CC e encoder para prática de sistemas de controle em engenharia | — | — | Ciência e Natura (UFSM) | https://periodicos.ufsm.br/cienciaenatura/article/view/92211 | Mini bancada com motor DC e encoder para práticas de controle. |
| 30 | Desenvolvimento de uma Plataforma Didática de Baixo Custo para Práticas de Controle de Velocidade de Motor CC | Torga | — | Monografia, UFOP | https://www.monografias.ufop.br/bitstream/35400000/1014/1/MONOGRAFIA_DesenvolvimentoPlataformaDid%C3%A1tica.pdf | Plataforma didática de baixo custo para controle de velocidade de motor CC. |
| 31 | Controle de Velocidade de Motor de Corrente Contínua | Silva | — | Monografia, UFGD | https://repositorio.ufgd.edu.br/jspui/bitstream/prefix/5883/1/DenerCarvalhoFariadaSilva.pdf | Controle PWM de motor DC com Arduino e componentes de baixo custo/reciclados. |
| 32 | Proposta de Plataforma Didática para Identificação e Modelagem de Motores de Corrente Contínua | — | — | Revista Valore | https://revistavalore.emnuvens.com.br/valore/article/view/985 | Plataforma com sensores para medição de variáveis de motor CC, permitindo identificação e modelagem. |
| 33 | Bancada didática de baixo custo para o ensino de Teoria de Controle | Vidal | 2023 | Monografia, UFOP | https://monografias.ufop.br/ | Bancada especificamente para ensino de Teoria de Controle com Arduino. |
| 34 | Simulação e prototipagem de baixo custo como apoio ao ensino de Engenharia | Revoredo | 2025 | Revista de Ensino de Engenharia (ABENGE) | https://revista.abenge.org.br/ | **Publicação da UERJ.** Simulação e prototipagem de baixo custo para ensino de engenharia. |
| 35 | Plataforma Didática Para Avaliação Rápida e Experimental de Estratégias de Controle em Eletrônica de Potência | — | 2018 | ResearchGate | https://www.researchgate.net/publication/328360927 | Plataforma para avaliação experimental de estratégias de controle em eletrônica de potência. |

---

## 4. ESP8266 / ESP32 para Ensino de Controle

Trabalhos que usam especificamente a família ESP para educação.

| # | Título | Autores | Ano | Veículo | URL | Descrição |
|---|---|---|-----|---|-----|---|
| 36 | Microcontrollers programming for control and automation in undergraduate biotechnology engineering education | Márquez-Vera, Martínez-Quezada et al. | 2023 | Digital Chemical Engineering (Elsevier) | https://www.sciencedirect.com/science/article/pii/S2666835123000518 | ESP32 como ferramenta de ensino para aquisição de sinais, processamento e teoria de controle. 45 citações. |
| 37 | Control engineering remote lab: design and hands-on practice with a DC motor speed controller | Ortega | 2023 | Encuentro Internacional de Educación en Ingeniería | https://acofipapers.org/ | Lab remoto com ESP32 para PID de motor DC. Alunos testam controladores remotamente. |
| 38 | Comparative Analysis of Robotic Arm Efficiency: PID and Fuzzy-PID Control using ESP8266 Integration | Crisnapati, Susila, Aryanto et al. | 2024 | IEEE Conference on Cybernetics and Computational Intelligence | https://ieeexplore.ieee.org/ | PID com ESP8266 + motores DC + encoders rotativos. Mesma família de MCU do Girino. |
| 39 | IOT Based Induction Motor PID Speed Control System Using Ziegler-Nichols Method | Harahap, Setyawan et al. | 2025 | Journal of Engineering Science and Technology | https://jestec.taylors.edu.my/ | **NodeMCU ESP8266** com encoder para controle PID via IoT. App Blynk para monitoramento. Arquitetura quase idêntica ao Girino. |
| 40 | Exploring the Pedagogical Potential of ESP32 as a Teaching Tool for IoT in Residential Automation | Lisboa, Silva et al. | 2024 | CBA (SBA) | https://sba.org.br/ | ESP32 como ferramenta didática de baixo custo. Abordagem Educação 5.0. |

---

## 5. Simulação vs Hardware Real

Trabalhos comparando ensino via simulação vs hardware físico.

| # | Título | Autores | Ano | Veículo | URL | Descrição |
|---|---|---|-----|---|-----|---|
| 41 | Simulation in Engineering Education: The Transition from Physical to Virtual Laboratories | — | 2024 | Simulation (Sage) | https://journals.sagepub.com/doi/10.1177/00375497241229757 | Revisão da transição de labs físicos para virtuais. Avalia o valor da experimentação hands-on. |
| 42 | Impact of Simulation-Based and Hands-On Teaching Methodologies on Students' Learning | — | — | ASEE | https://peer.asee.org/impact-of-simulation-based-and-hands-on-teaching-methodologies-on-students-learning-in-an-engineering-technology-program.pdf | Comparação direta simulação vs hands-on em cursos de engenharia. |
| 43 | Teaching devices and controls using Arduino and MATLAB/Simulink | Sheng | 2018 | IEEE ICCA | https://ieeexplore.ieee.org/document/8444281 | Aborda comparação simulação vs hardware. Arduino com Simulink Support Package. 17 citações. |
| 44 | Development and outcomes of teaching PID control in classroom with hands-on learning experience | Tran, Sun, Guan, Saeed et al. | 2019 | IEEE CCTA | https://ieeexplore.ieee.org/document/8801920 | Ensino hands-on de PID com Arduino. Compara desempenho simulação vs hardware real. |
| 45 | A low-cost Matlab-based educational platform for teaching robotics | Castañeda, Ruiz-Olaya | 2016 | IEEE Latin American Robotics Symposium | https://ieeexplore.ieee.org/document/7814567 | Plataforma MATLAB com Hardware-in-the-Loop (HIL). Compara controle simulado vs real. |

---

## 6. Revisões Sistemáticas e Surveys

| # | Título | Autores | Ano | Veículo | URL | Descrição |
|---|---|---|-----|---|-----|---|
| 46 | Virtual and remote labs in control education: A survey | Heradio, de la Torre, Dormido | 2016 | Annual Reviews in Control, 42, 63–84 | https://www.sciencedirect.com/science/article/pii/S1367578816300786 | **Survey mais citado (307 citações)** sobre labs virtuais e remotos para educação em controle. Referência essencial. |
| 47 | Open and low-cost virtual and remote labs on control engineering | Sáenz, Chacón, De La Torre, Visioli et al. | 2015 | IEEE Access, 3, 814–823 | https://ieeexplore.ieee.org/document/7107026 | Framework para labs remotos de controle. Inclui experimentos com motor DC. 203 citações. |
| 48 | Open-source hardware in education: A systematic mapping study | Heradio, Chacon, Vargas, Galan, Saenz et al. | 2018 | IEEE Access, 6, 72094–72103 | https://ieeexplore.ieee.org/document/8493059 | Revisão sistemática de 100+ papers sobre hardware open-source na educação. 84 citações. |
| 49 | Open-source remote laboratory experiments for controls engineering education | Reid, Burridge, Lowe et al. | 2022 | Int. J. Mechanical Engineering Education (Sage) | https://journals.sagepub.com/doi/abs/10.1177/03064190211073480 | Lab remoto open-source com motor DC. Estudantes interagem com hardware remotamente. 53 citações. |

---

## 7. Laboratórios Remotos

| # | Título | Autores | Ano | Veículo | URL | Descrição |
|---|---|---|-----|---|-----|---|
| 50 | Integration of a Remote PID Motor Speed Control Experiment with Teaching in Engineering Education | Wang, Zhu et al. | — | Semantic Scholar | https://www.semanticscholar.org/paper/Integration-of-a-remote-PID-motor-speed-control-in-Wang-Zhu/aa672fa55f4bc74d2f7dccafd14dee3db4cb6cac | Lab remoto wiki-based com aprendizado colaborativo para experimentos de PID. |
| 51 | Developing a Remote Laboratory System of Stepper Motor for Engineering Education | — | 2020 | Journal of Science Education and Technology (ERIC) | https://eric.ed.gov/?id=EJ1303810 | Lab remoto de baixo custo para motor de passo via dispositivo móvel. |

---

## 8. TCLab — Referências Adicionais

O TCLab é o caso de sucesso mais relevante como modelo de publicação para o Girino.

| # | Título | Autores | Ano | Veículo | URL |
|---|---|---|-----|---|-----|
| 52 | Benchmark Temperature Microcontroller for Process Dynamics and Control | Park, Martin, Kelly, Hedengren | 2020 | Computers & Chemical Engineering | https://apm.byu.edu/prism/uploads/Members/2020_park_tclab.pdf |
| 53 | PID Control with TCLab: A Unified Experiment for Undergraduates | Oliveira, Cunha | 2025 | IFAC ACE 2025 | https://doi.org/10.1016/j.ifacol.2025.08.050 |
| 54 | Introducing Digital Controllers to Undergraduate Students Using the TCLab Arduino Kit | Moura Oliveira, Hedengren, Rossiter | 2020 | 21st IFAC World Congress | https://www.sciencedirect.com/science/article/pii/S2405896320334224 |
| 55 | Pocket-Sized Portable Labs: Control Engineering Practice Made Easy | Moura Oliveira, Soares, Cardoso | 2022 | IFAC ACE 2022 | https://doi.org/10.1016/j.ifacol.2022.09.272 |

---

## 9. Veículos Recomendados para Publicação do Girino

### Brasil (prioridade)

| Veículo | Sigla | Organização | Tipo | URL | Observações |
|---|---|---|---|---|---|
| Congresso Brasileiro de Educação em Engenharia | COBENGE | ABENGE | Congresso | https://cobenge26.abenge.org.br/ | 54ª edição em 2026 (PUC-MG). Principal fórum brasileiro de educação em engenharia. |
| Congresso Brasileiro de Automática | CBA | SBA | Congresso | https://sba.org.br/ | Principal congresso brasileiro de automática. Já publicou trabalhos sobre plataformas didáticas. |
| Simpósio Brasileiro de Automação Inteligente | SBAI | SBA | Simpósio | https://sba.org.br/ | Já publicou bancada didática para controle de motor (2019). |
| Revista Brasileira de Ensino de Engenharia | RBEE | ABENGE | Periódico | https://revista.abenge.org.br/ | Periódico direto de educação em engenharia. |
| Revista Brasileira de Ensino de Física | RBEF | SBF | Periódico | https://rbef.scielo.br | Já publicou experimentos com Arduino. |
| Encontro Nacional de Engenharia de Produção | ENEGEP | ABEPRO | Congresso | — | Às vezes inclui papers de educação em engenharia. |

### Internacional

| Veículo | Tipo | Observações |
|---|---|---|
| IEEE EDUCON (Global Engineering Education Conference) | Congresso | MotoShield foi publicado aqui. |
| IEEE FIE (Frontiers in Education) | Congresso | Excelente para plataformas educacionais. |
| IFAC ACE (Advances in Control Education) | Congresso | Especializado em educação em controle. TCLab publicado aqui. |
| HardwareX (Elsevier) | Periódico | Open-source hardware. OpenMCT publicado aqui. |
| Computer Applications in Engineering Education (Wiley) | Periódico | Papers de Arduino + Simulink. |
| Electronics (MDPI) | Periódico | Open access. Publicou PID controller papers. |
| International Journal of Engineering Education | Periódico | Amplo escopo de educação em engenharia. |

---

## 10. Diferenciais do Girino frente ao Estado da Arte

| Aspecto | Trabalhos Existentes | Girino |
|---|---|---|
| Microcontrolador | Arduino UNO/Mega, Raspberry Pi, Teensy | **ESP8266 WROOM** (Wi-Fi nativo) |
| Conectividade | Nenhuma ou via shield externo | **Wi-Fi embutido + OTA** |
| Interface | MATLAB/Simulink ou serial | **API REST + interface web embarcada** |
| Atualização de firmware | Cabo USB | **OTA via ElegantOTA** |
| Licença | Variada (alguns NC) | **Tripla: GPL-3.0 + CERN-OHL-S-2.0 + CC-BY-SA-4.0** |
| Contexto | Majoritariamente EUA/Europa | **Brasil — LaRA/UERJ** |
| Encoder | Vários modelos | **LPD3806-600BM (600 PPR)** |
| Custo | $30–350 | **<$20 (componentes)** |

---

## 11. Papers na RBEF (Revista Brasileira de Ensino de Física)

Nenhum paper na RBEF combina motor DC + encoder + PID. A RBEF tem forte tradição com Arduino mas foca em aquisição de dados e sensores.

| # | Título | Autores | Ano | DOI | Descrição |
|---|---|---|-----|-----|---|
| 56 | Determinación del rendimiento de un motor de Stirling usando Arduino | Savall-Alemany et al. | 2020 | https://doi.org/10.1590/1806-9126-RBEF-2020-0279 | Arduino + sensores em motor Stirling. Baixo custo. |
| 57 | Potência e força eletromotriz em um gerador didático de corrente alternada | Alves et al. | 2022 | https://doi.org/10.1590/1806-9126-RBEF-2021-0379 | Motor com controle de rotação. Medição de EMF. |
| 58 | Uma aula sobre conversão de energia utilizando bicicleta, motor, alternador e lâmpada | Borges, Dickman, Vertchenko | 2018 | https://doi.org/10.1590/1806-9126-RBEF-2017-0215 | Motor em experimento didático. |
| 59 | Motor elétrico — SimuFísica® | Souza, Oliveira, Luiz | 2024 | https://doi.org/10.1590/1806-9126-RBEF-2023-0219 | Simulador de motor para ensino. |
| 60 | Sistema automatizado para medición del coeficiente de fricción estática | González-Laprea, Santiago | 2021 | https://doi.org/10.1590/1806-9126-RBEF-2021-0056 | Arduino + motor + sensores para física. |
| 61 | A placa Arduino: uma opção de baixo custo para experiências de física | Souza et al. | 2011 | https://doi.org/10.1590/S1806-11172011000100026 | Paper fundacional Arduino na RBEF. |
| 62 | Física com Arduino para iniciantes | Cavalcante et al. | 2011 | https://doi.org/10.1590/S1806-11172011000400018 | Arduino para automação e aquisição de dados. |
| 63 | Strain and deformation measurement using Arduino | Silva et al. | 2019 | https://doi.org/10.1590/1806-9126-RBEF-2018-0206 | Condicionamento de sinal com Arduino. |
| 64 | Kit experimental com Arduino para ensino de Física Moderna | Silveira, Girardi | 2017 | https://doi.org/10.1590/1806-9126-RBEF-2016-0287 | Kit de baixo custo com interface. |
| 65 | Física experimental com Arduino: ondas em uma corda | Sousa Jr. et al. | 2020 | https://doi.org/10.1590/1806-9126-RBEF-2020-0177 | Otimização de ADC e timing. |
| 66 | Kit experimental com Arduino para oscilações em tempo real | Matos Pereira, da Silva | 2021 | https://doi.org/10.1590/1806-9126-RBEF-2021-0186 | Visualização em tempo real. |
| 67 | Práticas experimentais de Física a distância: Millikan com Arduino | Barros, Dias | 2019 | https://doi.org/10.1590/1806-9126-RBEF-2019-0049 | **Controle remoto de experimento via web.** Filosofia similar ao Girino. |
| 68 | Sismógrafo empregando sensores piezoelétricos em Arduino | Amorim et al. | 2021 | https://doi.org/10.1590/1806-9126-RBEF-2021-0267 | Aquisição de dados com Arduino. |

### Revisões sistemáticas

| # | Título | Autores | Ano | URL |
|---|---|---|-----|-----|
| 69 | Contribuições do Arduino no Ensino de Física: revisão sistemática | — | ~2018 | https://bia.ifpi.edu.br/jspui/handle/123456789/4839 |
| 70 | Arduino no Ensino de Física: Revisão Sistemática de Literatura | UFPA | ~2022 | https://www.periodicos.ufpa.br/index.php/revistaamazonia/article/view/12175 |

---

## 12. Veículos Brasileiros Recomendados (Prioridade para Publicação)

| Veículo | Sigla | Tipo | Observações |
|---|---|---|---|
| Congresso Brasileiro de Educação em Engenharia | COBENGE | Congresso | 54ª edição em 2026. Principal fórum brasileiro. |
| Congresso Brasileiro de Automática | CBA | Congresso | Já publicou plataformas didáticas similares. |
| Revista Brasileira de Ensino de Física | RBEF | Periódico | **Lacuna clara** — nenhum paper sobre motor + encoder + PID. |
| Revista Brasileira de Educação em Engenharia | RBEE | Periódico | Foco direto em educação em engenharia. |
| Simpósio Brasileiro de Automação Inteligente | SBAI | Simpósio | Já publicou bancada didática para motor CC (2019). |
| Ciência e Natura (UFSM) | — | Periódico | Publicou mini bancada motor + encoder (2025). |

Ver estratégia detalhada de publicação em [`analise-comparativa.md`](analise-comparativa.md#6-estratégia-de-publicação-recomendada).

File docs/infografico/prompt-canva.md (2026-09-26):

# Prompt para a IA do Canva — infográfico 60 × 15 cm

Uso: no Canva Pro, crie um design em **Custom size → 60 × 15 cm**, suba `foto-bancada.jpg`, `infografico-uerj-sem-muros-60x15.png` (referência) e, no Brand Kit, as cores e as fontes de `fontes/` (Source Sans 3). Cole o prompt abaixo na IA e substitua os textos gerados pelos textos exatos do prompt. QR: Apps → QR Code → `github.com/italorosq/Girino`. Exporte PDF Print para a gráfica.

Atenção: a exportação PNG do Canva pode sair abaixo de 300 dpi; para o SDA, use o PNG de `docs/images/` (mesmo layout, 7087 × 1772 px).

---

Crie um infográfico horizontal (banner) de 60 × 15 cm, em português do Brasil, sobre um projeto acadêmico de engenharia, para a 23ª Semana de Graduação / 34ª UERJ Sem Muros. Público: banca e visitantes. Estilo institucional, técnico e sóbrio — nada infantil, nada de clip-art, sem sombras fortes nem excesso de gradientes. Fundo geral #E4EBF3; painéis brancos com borda fina #D9E3EF e cantos arredondados.

TEMA: modernização das plataformas robóticas do LaRA (Laboratório de Robótica e Automação — UERJ / CETREINA / EIC). O Girino é o PRIMEIRO MÓDULO ENTREGUE dessa modernização — não é um projeto separado.

Título (usar exatamente): "Modernização de Plataformas Robóticas e Desenvolvimento de Infraestrutura para Experimentação em Algoritmos de Robótica".

LAYOUT — 6 painéis lado a lado, com pequenos espaços entre eles (~0,1 cm) e estas larguras relativas:
1. Identidade — 15,6% (fundo azul-escuro #0B2C57, texto branco)
2. Problema — 12,7% (barra vermelha #C0392B)
3. Tese e Objetivo — 15,6% (barra azul #1660A8)
4. Método — 22,0% (barra azul #1660A8)
5. Resultados — 19,1% (barra verde-água #0E9594)
6. Impacto — 14,2% (barra verde-água #0E9594)
Cada painel tem uma barra vertical colorida de ~14 px ao lado do título da seção. Toques sutis de vida: sombra leve nos painéis, faixa de fundo tingida no cabeçalho de cada painel na cor da seção (~6% de opacidade), ícones dentro de badges circulares claros, chips com preenchimento tingido, e nos cartões de números um numeral gigante "fantasma" ao fundo (~7% de opacidade). Ícones lineares, traço fino, sem preenchimento.

PAINEL 1 — IDENTIDADE (azul-escuro #0B2C57, texto branco):
- Etiqueta no topo, em âmbar #F2A100: EIC · CETREINA/UERJ · LaRA
- Título acima, grande (ocupa cerca de 6 linhas)
- Subtítulo: Modernizar e manter o que a instituição já tem: o Girino como primeiro produto e o caminho documentado para quem vier depois.
- Quatro chips: Modernizar o que existe · Girino: primeiro produto · Plataforma aberta · Formação do bolsista
- Na base: um QR code branco com a legenda "Código aberto" (apontando para github.com/italorosq/Girino) e um mascote discreto de girino (tadpole) em traço fino branco, bem apagado, como marca d'água.

PAINEL 2 — PROBLEMA (vermelho #C0392B), 4 itens com ícones lineares:
1. Equipamento preservado e fora de uso — A estrutura continua íntegra, mas o sistema de controle envelhece, o suporte do fabricante acaba e as peças saem de linha. (ícone: base móvel com braço)
2. Camada de controle fechada — O que existe não admite modificação, expansão nem integração com as ferramentas atuais. (ícone: cadeado sobre conector)
3. Tentativas anteriores abandonadas — A curva de aprendizado inicial não se sustentou e o equipamento voltou para a prateleira. (ícone: linha do tempo interrompida por um X)
4. Formação sem prática — Controle, cinemática e processamento de sinais estudados sem contato com hardware real, ruído e limitações. (ícone: livro aberto com circuito)

PAINEL 3 — TESE E OBJETIVO (azul #1660A8):
- Duas premissas em destaque (com aspas decorativas grandes ao fundo, bem apagadas):
  "Manter o equipamento em uso vale tanto quanto adquiri-lo."
  "Baixar a barreira de entrada é o que devolve o equipamento ao uso."
- OBJETIVO: Modernizar e manter as plataformas do laboratório, com controladores abertos de baixo custo, e transformar o processo em formação técnica para o bolsista e em recurso aberto para a comunidade acadêmica. O Girino é o primeiro produto. (destacar a última frase)
- Nota de rodapé, em itálico: Bolsista recém-iniciado e sem verba de material: o que já roda usa os componentes que o laboratório tem em estoque.

PAINEL 4 — MÉTODO (azul #1660A8), 4 etapas numeradas em círculo:
1. Caracterizar o que existe — Entender a estrutura, medir o que ainda funciona e registrar o que precisa ser trocado.
2. Começar pelo Girino — Um motor, um driver e um encoder, com interface no navegador, para validar o caminho em escala pequena.
3. Avançar por etapas — Cada função nova é validada em bancada antes de entrar no equipamento, e o que dá errado é registrado junto com a solução.
4. Documentar enquanto acontece — Esquemas, medições, listas de materiais e código aberto, para que a próxima pessoa não recomece do zero.
- Dois chips: "Ciclos: bancada → plataforma montada → uso real" e "Adaptações mecânicas impressas em 3D no próprio laboratório"

PAINEL 5 — RESULTADOS (verde-água #0E9594), 4 métricas grandes em grade 2 × 2 (número gigante + rótulo):
- 2 — malhas PID em bancada: velocidade e posição, com auto-sintonia embarcada
- 3 — métodos de sintonia comparados: Ziegler-Nichols, Tyreus-Luyben e Cohen-Coon
- 600 — pulsos por revolução no encoder incremental lido por interrupção
- 0 — programas a instalar: o controle é feito pelo navegador, sem internet
- Abaixo das métricas, uma FOTO REAL da bancada (anexada): motor DC com encoder e roda, driver e caixa impressa em 3D sobre base de acrílico. NÃO substituir por banco de imagens. Legenda sobre a foto: "Bancada de validação do Girino — ESP8266 + driver MOSFET + encoder LPD3806-600BM"
- Faixa escura no pé do painel: Sem verba de material: componentes do estoque do laboratório · PID e auto-sintonia validados em bancada · placa de circuito impresso em projeto no KiCad e caixa em 3D nas próximas etapas

PAINEL 6 — IMPACTO (verde-água #0E9594), 4 itens numerados:
1. Equipamento de volta ao uso — Em vez de comprar de novo, manter e modernizar o que a instituição já pagou.
2. Entrada barata para a robótica — O Girino serve a disciplinas, extensão e trabalhos de conclusão, e a bancada é replicável em outros laboratórios.
3. Formação técnica — O bolsista percorre o ciclo completo de um projeto de sistemas embarcados, da medição de bancada à documentação de entrega.
4. Método replicável — Caracterizar o que existe, adotar arquitetura aberta e documentar em processo contínuo, o que serve a outros equipamentos da instituição.
- Faixa âmbar no pé: Diversidade que inspira, conhecimento que transforma

HIERARQUIA DE TEXTO (para 60 × 15 cm, legível a ~1,5 m):
- Título do trabalho: ~19–20 pt (≈ 7,5 mm de altura)
- Títulos dos painéis: ~14 pt (≈ 5 mm)
- Corpo: 11–12 pt (≈ 3,8–4,2 mm) — nunca abaixo de ~10 pt
- Números das métricas: ~36 pt (≈ 12,7 mm)
- Chips: ~10 pt

TIPOGRAFIA E CORES:
- Fonte sem serifa Source Sans 3 (ou Source Sans Pro)
- Paleta: #0B2C57 (azul-escuro), #1660A8 (azul), #0E9594 (verde-água), #F2A100 (âmbar), #C0392B (vermelho), #D9E3EF (borda), #E4EBF3 (fundo)

FATOS QUE PODEM SER AFIRMADOS (não inventar além disso): firmware em modo hardware real (sem simulador); PID de velocidade e de posição em malha fechada com auto-sintonia embarcada, validados em bancada; 3 métodos de sintonia comparados; encoder de 600 pulsos por revolução lido por interrupção; controle pelo navegador, sem instalar nada e sem internet.

NÃO INCLUIR: nomes de autores, orientador, curso ou unidade acadêmica (ficam no cabeçalho do pôster, fora do infográfico); licenças; referências bibliográficas; metragem do laboratório; modelo, dimensões ou graus de liberdade dos equipamentos a modernizar; qualquer número, resultado ou prêmio que não esteja neste prompt.

---

## Refinamentos (se a IA do Canva fugir do alvo)

- "Mantenha este layout, mas troque toda a tipografia por Source Sans Pro e reduza as sombras."
- "O painel Resultados deve ficar exatamente 2 × 2 com 4 cartões iguais; aumente os números em 20%."
- "Deixe os ícones lineares, traço fino, dentro de círculos claros, sem preenchimento."
- "Aumente todo o corpo de texto em ~10% — precisa ser legível a 1,5 m no banner."

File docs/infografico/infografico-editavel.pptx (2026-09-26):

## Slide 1

EIC · CETREINA/UERJ · LaRA

Modernização de Plataformas Robóticas e Desenvolvimento de Infraestrutura para Experimentação em Algoritmos de Robótica

Modernizar e manter o que a instituição já tem: o Girino como primeiro produto e o caminho documentado para quem vier depois.

Modernizar o que existe

Girino: primeiro produto

Plataforma aberta

Formação do bolsista

Código aberto
github.com/italorosq/Girino

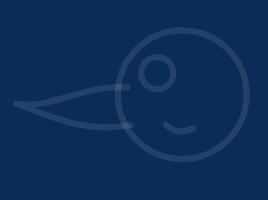
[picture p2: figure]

Problema

Equipamento preservado e fora de uso

A estrutura continua íntegra, mas o sistema de controle envelhece, o suporte do fabricante acaba e as peças saem de linha.

Camada de controle fechada

O que existe não admite modificação, expansão nem integração com as ferramentas atuais.

Tentativas anteriores abandonadas

A curva de aprendizado inicial não se sustentou e o equipamento voltou para a prateleira.

Formação sem prática

Controle, cinemática e processamento de sinais estudados sem contato com hardware real, ruído e limitações.

Tese e Objetivo

Manter o equipamento em uso vale tanto quanto adquiri-lo.

Baixar a barreira de entrada é o que devolve o equipamento ao uso.

OBJETIVO

Modernizar e manter as plataformas do laboratório, com controladores abertos de baixo custo, e transformar o processo em formação técnica para o bolsista e em recurso aberto para a comunidade acadêmica.
O Girino é o primeiro produto.

Bolsista recém-iniciado e sem verba de material: o que já roda usa os componentes que o laboratório tem em estoque.

Método

Ciclos: bancada → plataforma montada → uso real

Adaptações mecânicas impressas em 3D no próprio laboratório

Caracterizar o que existe

Entender a estrutura, medir o que ainda funciona e registrar o que precisa ser trocado.

Começar pelo Girino

Um motor, um driver e um encoder, com interface no navegador, para validar o caminho em escala pequena.

Resultados

Bancada de validação do Girino — ESP8266 + driver MOSFET + encoder LPD3806-600BM

Sem verba de material: componentes do estoque do laboratório · PID e auto-sintonia validados em bancada · placa de circuito impresso em projeto no KiCad e caixa em 3D nas próximas etapas

2

malhas PID em bancada: velocidade e posição, com auto-sintonia embarcada

3

métodos de sintonia comparados: Ziegler-Nichols, Tyreus-Luyben e Cohen-Coon

Impacto

Equipamento de volta ao uso

Em vez de comprar de novo, manter e modernizar o que a instituição já pagou.

Entrada barata para a robótica

O Girino serve a disciplinas, extensão e trabalhos de conclusão, e a bancada é replicável em outros laboratórios.

Formação técnica

O bolsista percorre o ciclo completo de um projeto de sistemas embarcados, da medição de bancada à documentação de entrega.

Método replicável

Caracterizar o que existe, adotar arquitetura aberta e documentar em processo contínuo, o que serve a outros equipamentos da instituição.

Diversidade que inspira, conhecimento que transforma

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
pulsos por revolução no encoder incremental lido por interrupção

0

programas a instalar: o controle é feito pelo navegador, sem internet

Avançar por etapas

Cada função nova é validada em bancada antes de entrar no equipamento, e o que dá errado é registrado junto com a solução.

Documentar enquanto acontece

Esquemas, medições, listas de materiais e código aberto, para que a próxima pessoa não recomece do zero.

600

0

3

4

3


4

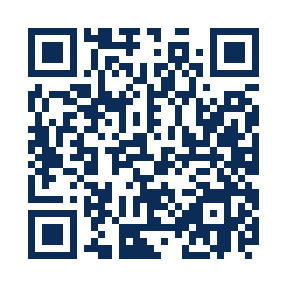
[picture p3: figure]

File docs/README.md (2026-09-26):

# Documentação — Girino

Documentação técnica da plataforma didática Girino.

## Guias

| Documento | Descrição |
|---|---|
| [Início Rápido](getting-started.md) | Setup completo do zero |
| [Montagem do Hardware](hardware-assembly.md) | Passo a passo de montagem |
| [Guia do Firmware](firmware-guide.md) | Compilação e gravação |
| [Atualização OTA](ota-update-guide.md) | Atualizar firmware via Wi-Fi |

## Pesquisa e Publicação

| Documento | Descrição |
|---|---|
| [Referências de Pesquisa](referencias-pesquisa.md) | Levantamento bibliográfico (~70 referências) para artigo |
| [Análise Comparativa](analise-comparativa.md) | Review dos trabalhos relacionados, gap analysis e estratégia de publicação |
| [Plano PID](plano-pid.md) | Métodos de sintonia, auto-tune, arquitetura e exemplos didáticos |

## Eventos

| Documento | Descrição |
|---|---|
| [Resumo UERJ Sem Muros](resumo-uerj-sem-muros.md) | Resumo do projeto para submissão à UERJ Sem Muros (1000–2000 caracteres) |
| [Infográfico UERJ Sem Muros](images/infografico-uerj-sem-muros.png) | Infográfico de divulgação do projeto (PNG, 1080×1350) |

## Recursos

- `images/` — Diagramas, esquemas de ligação, fotos
- `datasheets/` — Datasheets dos componentes utilizados

## Contribuindo com Documentação

- Use Markdown (`.md`) para todos os textos
- Imagens em `images/` com nomes descritivos
- Mantenha os guias atualizados quando o hardware ou firmware mudar

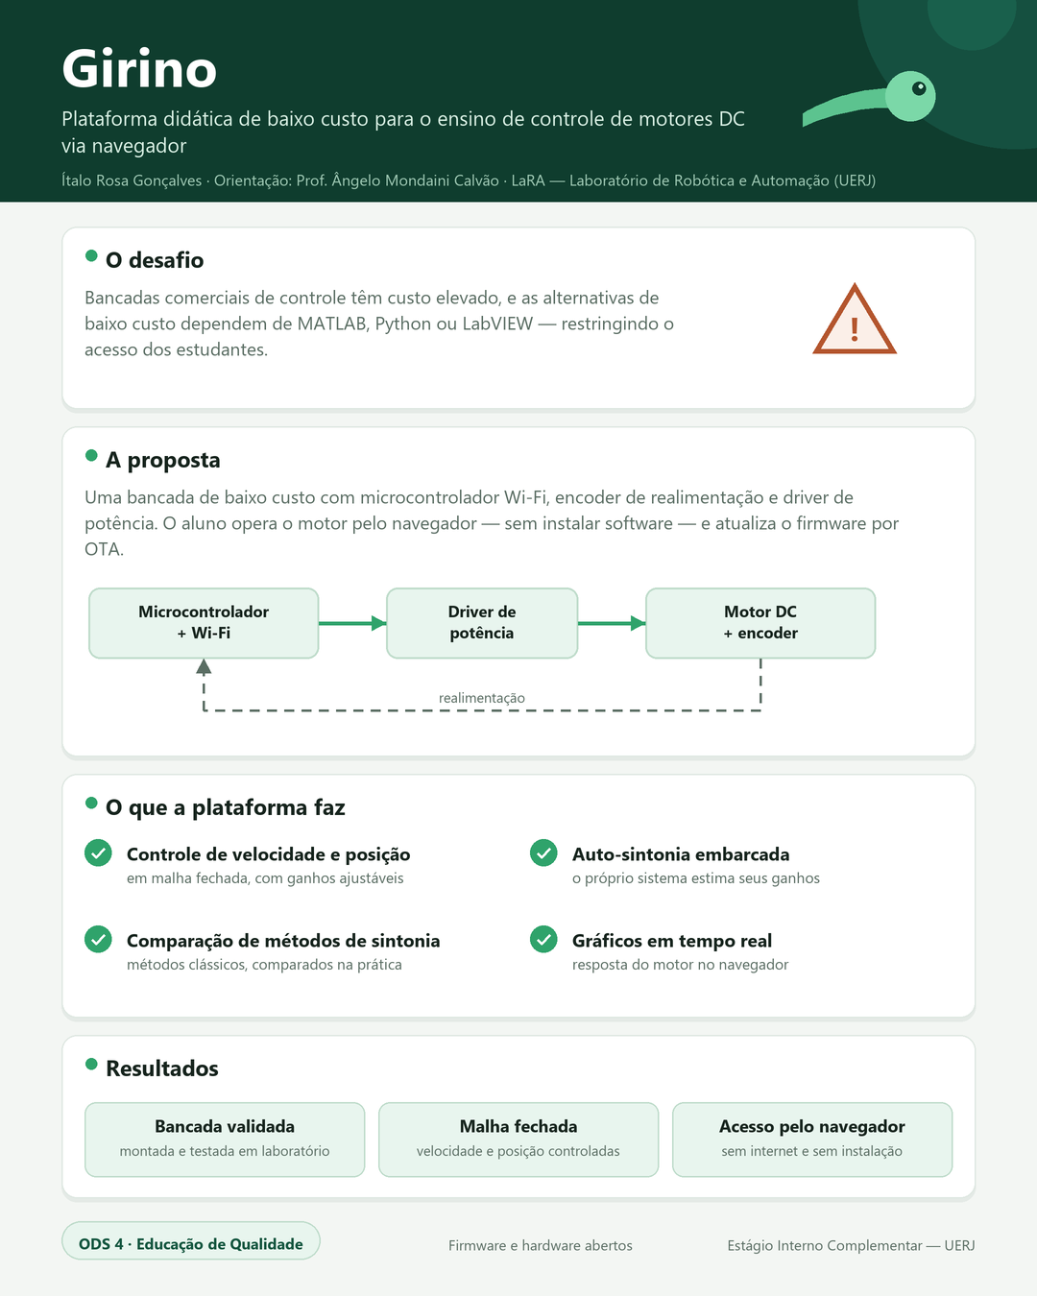
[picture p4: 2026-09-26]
docs/images/infografico-uerj-sem-muros.png

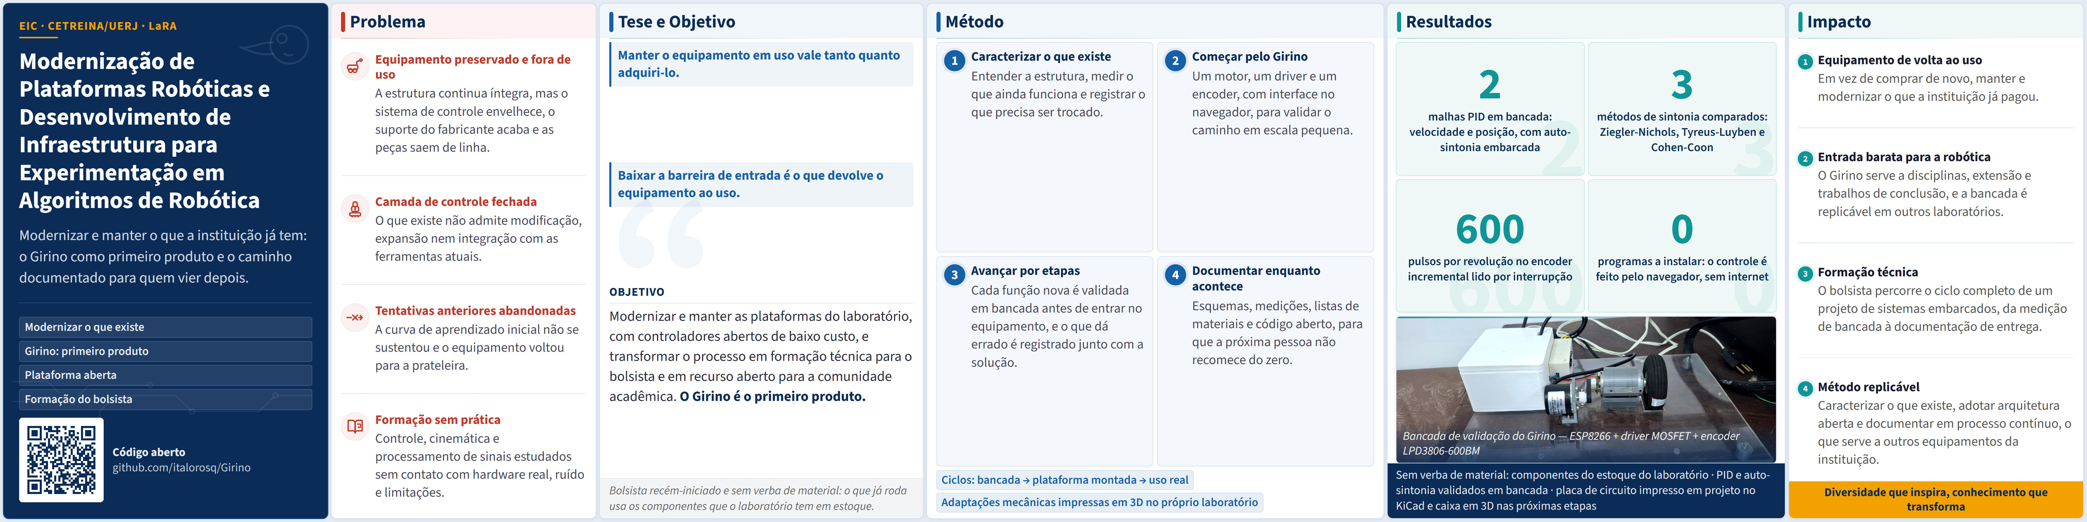
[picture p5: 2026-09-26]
docs/images/infografico-uerj-sem-muros-60x15.png

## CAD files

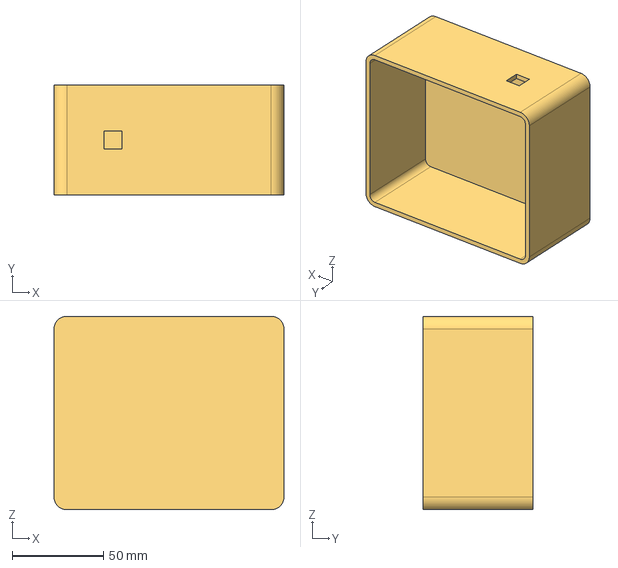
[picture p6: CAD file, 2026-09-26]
hardware/3d models/caixa.step
126.0 x 60.0 x 106.0 mm

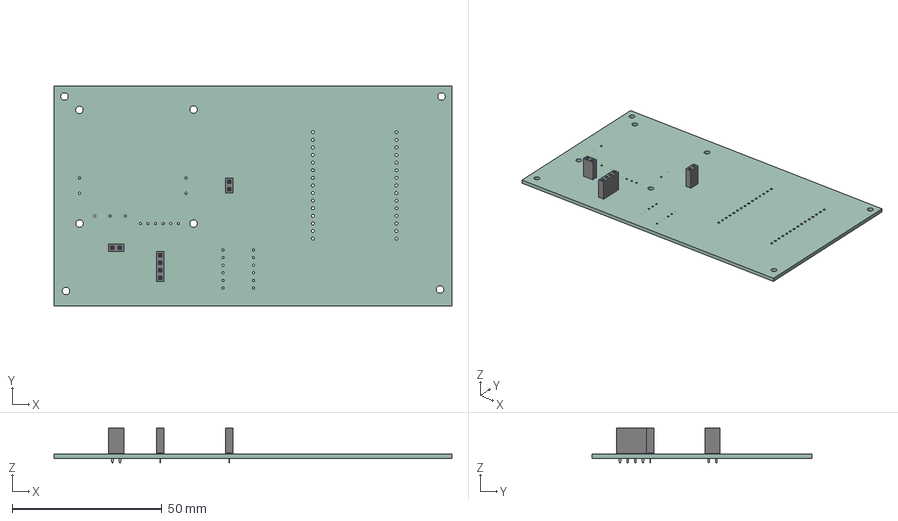
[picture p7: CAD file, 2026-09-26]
hardware/kicad/.step
133.0 x 73.5 x 11.6 mm
PinSocket_1x04_P2.54mm_Vertical
PinSocket_1x02_P2.54mm_Vertical x 2
pcb_copper
pcb_PCB

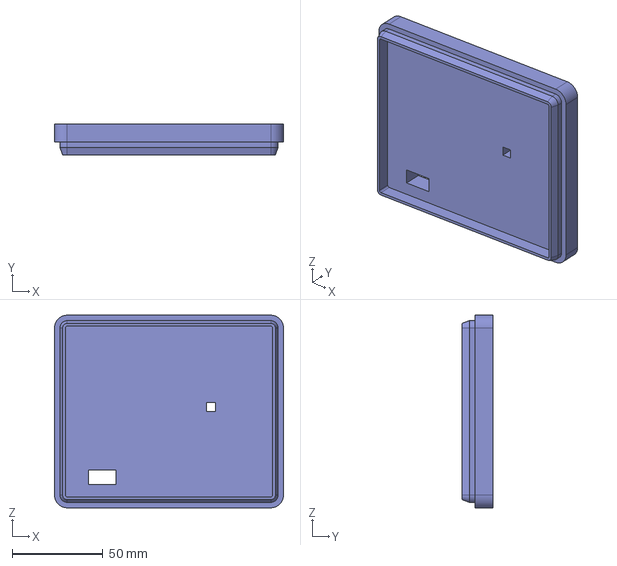
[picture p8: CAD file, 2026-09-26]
hardware/3d models/tampa.step
126.0 x 17.0 x 106.0 mm

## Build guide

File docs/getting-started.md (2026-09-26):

# Guia de Início Rápido — Girino

## Visão Geral

Este guia orienta você desde a montagem do hardware até o primeiro controle do motor via interface web.

## Pré-requisitos

### Ferramentas

- Computador com [VSCode](https://code.visualstudio.com/) + extensão [PlatformIO](https://platformio.org/)
- Cabo USB micro-B
- Ferro de solda (para montagem do hardware)

### Componentes

| Componente | Qtd | Notas |
|---|---|---|
| ESP8266 WROOM | 1 | Módulo com antena PCB |
| Encoder LPD3806-600BM | 1 | 600 pulsos/revolução |
| Módulo driver motor DC | 1 | Baseado em MOSFET |
| Módulo conversão de tensão | 1 | Para alimentação do circuito |
| Motor DC | 1 | Qualquer motor DC pequeno |
| Fonte de alimentação | 1 | Compatível com o motor e circuito |
| Cabos jumper | varios | Para conexões |
| Protoboard | 1 | Opcional — PCB recomendada |

## Passo 1: Montagem do Hardware

Siga o guia detalhado em [hardware-assembly.md](hardware-assembly.md).

### Esquema de Ligação Rápido

```
ESP8266 WROOM
├── D1 (GPIO5)  ← Encoder A (fio amarelo)
├── D2 (GPIO4)  ← Encoder B (fio verde)
├── D5 (GPIO14) → Motor DIR IN3
├── D6 (GPIO12) → Motor DIR IN4
├── D7 (GPIO13) → Motor PWM ENB
├── Vin          ← 5V (módulo conversão)
├── GND         ← GND comum
└── USB         ← Para gravação inicial
```

## Passo 2: Configurar o Firmware

```bash
# Clonar o repositório
git clone https://github.com/usuario/Girino.git
cd Girino/firmware

# Configurar credenciais WiFi
cp .env.example .env
# Editar .env com suas credenciais
nano .env
```

## Passo 3: Compilar e Gravar

```bash
# Conectar ESP8266 via USB

# Compilar e gravar
pio run -t upload

# Monitor serial (verificar saída)
pio device monitor
```

Você deverá ver no monitor serial:
```
=== Girino v0.1.0 ===
LaRA — Laboratório de Robótica e Automação
[Motor] Inicializado
[Encoder] Inicializado — LPD3806-600BM (600 PPR)
Conectando ao WiFi.... Conectado!
Servidor HTTP + OTA iniciado
Sistema inicializado com sucesso!
IP: 192.168.1.xxx
OTA: http://192.168.1.xxx/update
```

## Passo 4: Controlar via Web

1. Abra o navegador no endereço IP mostrado no serial
2. Use a interface web para controlar o motor
3. Acompanhe a leitura do encoder em tempo real

## Próximos Passos

- [Atualização OTA](ota-update-guide.md) — Atualizar firmware sem cabo USB
- [Exemplos didáticos](../examples/) — Aprender conceitos de controle
- [Montar a PCB](../hardware/) — Versão definitiva em placa de circuito

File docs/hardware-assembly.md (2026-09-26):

# Montagem do Hardware — Girino

## Lista de Materiais (BOM)

Ver lista completa em [`hardware/bom/`](../hardware/bom/).

## Ferramentas Necessárias

- Ferro de solda e solda
- Multímetro
- Alicate de corte e descascador de fios
- Chaves Philips e Allen

## Diagrama de Ligação

### ESP8266 WROOM — Pinagem

```
                    ┌──────────────┐
         (TX) GPIO1 │              │ GPIO3 (RX)
              GPIO5 │              │ GPIO4
         (D1) ←────│  ESP8266     │────→ (D2)
         Encoder A  │  WROOM      │ Encoder B
                    │              │
              GPIO14│              │ GPIO12
         (D5) ────→│              │←──── (D6)
         Motor IN3  │              │ Motor IN4
                    │              │
              GPIO13│              │ GPIO2
         (D7) ────→│              │←──── (D4)
         Motor ENB  │              │ LED onboard
            PWM     │              │
                    │              │
              3V3   │              │  GND
              3.3V  │              │  GND
                    └──────────────┘
```

### Encoder LPD3806-600BM

| Fio | Cor (típica) | Conexão |
|---|---|---|
| VCC | Vermelho | 5V |
| GND | Preto | GND |
| Canal A | Amarelo | GPIO5 (D1) + pull-up 4,7k para 3.3V |
| Canal B | Verde | GPIO4 (D2) + pull-up 4,7k para 3.3V |

#### ⚠️ Importante: saída em coletor aberto

O LPD3806-600BM tem **saída em coletor aberto** (open-collector): cada canal
não "empurra" o sinal para alto — apenas **puxa o pino para GND** quando o
transistor interno conduz. Sem um resistor de pull-up, o pino do ESP8266
fica **flutuando** e a leitura não funciona.

```
        VCC (5V) ──── LED interno do encoder
        VCC (5V) ──── coletor do transistor (via encoder)
                          │
                      saída A/B ──→ pino do ESP8266
                          │
                     GND (quando conduz)
```

Por isso **cada canal (A e B) precisa de um resistor de pull-up de 4,7k
(ou 10k) conectado ao 3.3V do ESP8266**:

```
  Saída A do encoder ──●────→ D1 (GPIO5)
                       │
                      [R] 4,7k
                       │
  3.3V do ESP8266 ─────┘   (idem para canal B em D2)
```

Regras de segurança:

1. **O pull-up vai para 3.3V, nunca para 5V.** Os GPIOs do ESP8266 não
   são tolerantes a 5V. Como a saída é coletor aberto, o transistor só
   conecta o pino ao GND — a tensão alta do sinal vem do pull-up, então
   mantendo o pull-up em 3.3V o sinal fica seguro.
2. **Por que não usar o pull-up interno do ESP8266?** Ele existe
   (`INPUT_PULLUP`), mas é fraco (~10k–50k, impreciso) e produz bordas
   de subida lentas — em RPM alto, a interrupção perde pulsos. O resistor
   externo de 4,7k dá bordas firmes e contagem confiável.
3. Os resistores já estão soldados na PCB do Girino (ver esquemático em
   `hardware/kicad/`). O firmware usa `pinMode(..., INPUT)` simples,
   confiando nos pull-ups externos.

### Driver do Motor

| Pino Driver | Conexão |
|---|---|
| INB1 (alias IN3) | GPIO14 (D5) |
| INB2 (alias IN4) | GPIO12 (D6) |
| ENB (PWM) | GPIO13 (D7) |
| VCC (Vm) | Fonte 12V do motor |
| VCC (Vcc) | 3.3V (lógica) |
| GND | GND comum |
| OUTB1 / OUTB2 | Motor DC |

Nota: os canais ENA/INA1/INA2/OUTA não são usados pela PCB e ficam
desconectados (ver nets do esquemático).

## Passo a Passo

### 1. Preparação da Fonte

1. Conectar o módulo de conversão de tensão à fonte principal
2. Ajustar a saída para 5V (para o ESP8266 e encoder)
3. Verificar tensão com multímetro

### 2. Montagem do Encoder

1. Fixar o encoder no eixo do motor
2. Conectar os fios conforme tabela acima
3. Verificar que os canais A e B estão em GPIOs com interrupção

### 3. Conexão do Driver do Motor

1. Conectar os pinos de controle ao ESP8266
2. Conectar a saída do driver ao motor DC
3. Alimentar o driver com tensão adequada ao motor

### 4. Conexão do ESP8266

1. Alimentar o ESP8266 com 3.3V (via regulador ou USB)
2. Conectar todos os GNDs em comum
3. Verificar todas as conexões com multímetro antes de ligar

## Verificação

Antes de prosseguir para o firmware:

1. ✅ Todas as conexões GND em comum
2. ✅ Tensões corretas em cada ponto
3. ✅ Nenhum curto-circuito entre VCC e GND
4. ✅ Encoder girando livremente com o motor
5. ✅ ESP8266 ligando (LED onboard piscando)

## Solução de Problemas

| Problema | Causa Provável | Solução |
|---|---|---|
| ESP8266 não liga | Alimentação inadequada | Verificar 3.3V no pino |
| Encoder não conta | Pinos errados ou pull-up ausente | Verificar GPIO5/GPIO4 e os resistores de pull-up 4,7k para 3.3V (coletor aberto exige pull-up externo) |
| Leitura do encoder instável / RPM errado | Pull-up fraco ou para 5V | Confirmar pull-up externo de 4,7k para **3.3V** (não 5V) |
| Motor não gira | Driver sem alimentação | Verificar VCC no driver |
| Motor gira errado | INB1/INB2 invertidos | Trocar conexões INB1 ↔ INB2 |

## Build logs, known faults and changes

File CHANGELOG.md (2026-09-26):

# Changelog

Todas as mudanças notáveis neste projeto serão documentadas neste arquivo.

O formato é baseado em [Keep a Changelog](https://keepachangelog.com/pt-BR/1.1.0/),
e este projeto adota [Versionamento Semântico](https://semver.org/lang/pt-BR/).

## [Unreleased]

### Adicionado
- Exemplo `05-pid-web-test` com firmware standalone para teste PID via interface web
- Painel web no exemplo com ajuste em tempo real de `setpoint`, `Kp`, `Ki`, `Kd` e grafico de resposta
- Controle PID em malha fechada no firmware (`pid.cpp`, 50 Hz, anti-windup, derivative-on-measurement)
- Auto-tune embarcado via relay feedback Åström-Hägglund (`pid_autotune.cpp`): identifica Ku e Tu
- Regras de sintonia Ziegler-Nichols, Tyreus-Luyben e Cohen-Coon (`pid_tuning_rules.cpp`)
- Endpoints REST `/api/pid/config`, `/api/pid/start`, `/api/pid/stop`, `/api/pid/autotune`, `/api/pid/tuning`, `/api/pid/tuning/apply` e `/api/pid/response`
- Campo `mode` no `/api/status` (`open-loop`/`pid`/`autotune`) para comparação entre malha aberta e fechada
- Controle de posição (ângulo) com PID bidirecional: `/api/position/config`, `/api/position/start`, `/api/position/stop` e `/api/position/zero`
- Modo **Posição** na interface web (alvo em graus, ganhos próprios, botão "Zerar Posição", gráfico em graus)
- `angle` (graus) no `/api/encoder` e no `/api/status`; campo `mode` aceita `position`
- `stations`, `ssid` e `ip` no `/api/status` (rede do Access Point)
- Exportação CSV do experimento gravado no ESP (`/api/pid/response`), com unidade rpm/graus
- Chart.js embarcado no LittleFS (`data/chart.umd.min.js`) — a interface funciona sem internet
- `scripts/load_env.py`: credenciais do `.env` injetadas corretamente na compilação
- Girino agora opera como **Access Point** (`GIRINO_AP`, `http://192.168.4.1`)
- Feedback do encoder: LED onboard pisca a cada pulso, telemetria serial de 1 Hz (`pulsos`, `p/s`, `rpm`, `ângulo`) e tile "Encoder" na interface com alerta quando o motor roda sem sinal
- Telemetria serial 2 Hz dos controladores ativos: `[PID] SP/RPM/Out`, `[Pos] Alvo/Ângulo/Out` e `[AutoTune] RPM/relay`
- Ganhos default do PID de velocidade calibrados para a bancada (Kp=0.08, Ki=0.25, Kd=0) e aviso na interface quando os ganhos estão zerados
- Console serial de comandos (`help`, `status`, `enc`, `motor`, `pid`, `pos`, `autotune`, `tune`) — controle completo da bancada sem Wi-Fi
- Auto-calibração do sentido motor/encoder: no primeiro movimento após o boot um pulso de teste detecta fiação invertida e corrige em software — "horário" sempre aumenta o ângulo, qualquer que seja a ligação dos fios
- Interface: botões Iniciar/Parar dentro dos painéis de PID e Posição, descrição de cada modo, passo a passo do controle de posição e nota de que o Auto-Tune sugere ganhos para a malha de velocidade
- Interface web redesenhada em **3 abas** (Velocidade / Posição / Manual): o Auto-Tune virou um sub-card dentro da aba Velocidade (fluxo direto identificar → sintonizar → testar), com leitura ao vivo **Setpoint / Medido / Erro / Saída PWM** em destaque, botão **PARAR** fixo no cabeçalho (segurança), tooltips didáticos em Kp/Ki/Kd e box colapsável "Como funciona o PID?"; layout responsivo em 2 colunas em telas ≥ 900px
- **Auto-Tune de posição** (relé simétrico ±d em torno do alvo em graus): identifica a malha de ângulo e gera ganhos em %/° (Ku = 4d/πa) direto para o PID de posição; sub-card próprio na aba Posição, timeout de 90 s (ciclos de posição são mais lentos) e leitura ao vivo do relay ± durante o experimento

### Alterado
- Pinagem de referencia alinhada para motor com `IN3`/`IN4` e `ENB`:
  - `GPIO14 (D5)` -> `IN3`
  - `GPIO12 (D6)` -> `IN4`
  - `GPIO13 (D7)` -> `ENB/PWM`
- Documentacao atualizada com a nova referencia de pinagem em `AGENTS.md`, `firmware/README.md`, `docs/getting-started.md` e `docs/hardware-assembly.md`
- Interface web (`app.js`) conectada ao firmware real (`USE_MOCK=false`); simulador mantido para testes sem hardware
- Leitura do encoder usa `INPUT` confiando nos pull-ups externos de 4,7k para 3.3V (saída coletor aberto do LPD3806)
- Comando manual via `/api/motor` desliga automaticamente PID e auto-tune
- Interface: botão "Aplicar ganhos" removido — os ganhos/setpoint/alvo são enviados ao firmware automaticamente (debounce de 600 ms) ao digitar, ao escolher um método de sintonia (ZN/TL/CC) nos resultados do Auto-Tune e antes do "Iniciar"; mudar o setpoint durante a execução ajusta o alvo ao vivo
- PID refatorado em núcleo único compartilhado entre velocidade (0..+100%) e posição (-100..+100%)
- `/api/pid/tuning` responde chaves minúsculas (`zn`/`tl`/`cc`), consistente com a interface
- Trocar de modo na interface cancela o experimento em andamento no firmware
- Setpoint de velocidade limitado a 3000 RPM (antes 1000) e defaults ajustados à bancada medida (zona morta ~60%, 100% ≈ 1950 RPM): Auto-Tune com amplitude 18% e bias 82% (relay 64–100%), setpoint padrão 1000 RPM, campo de setpoint na UI até 2400 RPM
- PWM do motor para 4 kHz com 8 bits (255 passos) — chiado do chaveamento mais discreto, dentro do orçamento ~1 MHz do PWM por software do ESP8266
- `/api/pid/config` e `/api/position/config` (GET) retornam agora `running`, `error` e `output` (e `measurement` no PID de velocidade); `/api/pid/autotune` (GET) inclui o `output` do relé — alimenta a leitura ao vivo da interface (endpoints de POST inalterados)
- `/api/pid/autotune` (POST) aceita o parâmetro `plant` (`speed` padrão | `position`): em posição usa `target` (graus) como centro da oscilação, relé ±amplitude e ignora `bias`; `autotuneStart()` assinatura nova `(plant, amp, bias, ciclos, setpoint)`; `/api/pid/tuning` e `/api/pid/tuning/apply` aplicam os ganhos no controlador da planta identificada; console serial ganhou `autotune pos <amp> <n> <graus>`

### Corrigido
- Simulador da interface (`USE_MOCK`): o laço de controle agora roda a 50 Hz (5 sub-passos de 20 ms por tick do gráfico, igual ao firmware) — antes simulava a 10 Hz e os ganhos do auto-tune oscilavam em ciclo-limite sustentado na simulação (na bancada convergem); o auto-tune do mock mede o envelope real da oscilação (como o firmware) em vez de usar amplitude estimada fixa
- Planta do mock fiel à bancada real: zona morta ~60% de duty (motor parado abaixo dela, roda-livre como o STOP do L298N), 100% ≈ 1950 RPM, acionamento mínimo ~230 RPM — malha aberta, PID de velocidade, PID de posição e os dois auto-tunes compartilham a mesma planta; o PID de posição com ela reproduz o creep/bang-bang da bancada (documentado na dica da aba Posição)
- Freio dinâmico no L298N para a malha de posição: `MOTOR_DIR_BRAKE` (IN3+IN4 HIGH) + `motorBrake()`; quando a saída do PID de posição está abaixo da zona morta do motor (`POS_MOTOR_DEADZONE_DUTY 60`), o firmware freia o eixo em vez de rodar-livre — mata a inércia do coast que causava o overshoot de cada chute do bang-bang (na simulação: de 1% para 99% do tempo dentro de ±2° do alvo); UI: tile ERRO da posição fica verde quando o erro está dentro da deadband (±2°)
- Posição: atuação em **passos discretos** perto do alvo (modo passo em 3 camadas): deadband/freio → passos curtos a `POS_SOFT_DUTY 65%` com direção pelo sinal do erro e pausa de freio entre passos (`POS_SOFT_KICK_TICKS 1` + `POS_SOFT_REST_TICKS 3` a 50 Hz) → longe, duty mínimo `POS_MIN_DRIVE_DUTY 62` acima da zona morta (pedidos fracos não travam no limiar). Correções no núcleo PID: teto do termo integral da posição (`POS_INTEGRAL_TERM_MAX 55`, abaixo da zona morta — sem rastejo com erro ~0) e teto da contribuição derivativa (`POS_DERIVATIVE_TERM_MAX 30`) — o D a toda velocidade inverteria a saída a cada tick e era a causa principal da caça ±35° medida na bancada; validação numérica: 100% do tempo na faixa ±2° com ganhos default e com ganhos do auto-tune (antes: 0%)
- **Posição v2 (validada em bancada, 9/9)**: o ciclo soco-100%/freio a 50 Hz levou o L298N ao **desligamento térmico** (eixo travou a 171° além do alvo) — duty da malha de posição limitado a `POS_MAX_DUTY 65` (nunca 100%), passos de 2 ticks + descanso de freio de 8 ticks (160 ms) para o driver esfriar; bancada: assentou a **1.8° do alvo com Out=0% e eixo travado**, estável; a caça ±35° de antes era o D explodindo + o driver desligando
- Interface: gráfico movido para o **topo da página** (largura total, abaixo das abas); abaixo dele o painel do modo ativo + status em 2 colunas (desktop) ou empilhados (mobile)
- **Otimização de overshoot validada na bancada (teste agressivo)**: (1) pulso de calibração de sentido amaciado — 70% × 50 ms + freio (`MOTOR_CALIB_*`): giro caiu de **416° para 32-104°** (antes parecia overshoot no gráfico logo ao iniciar); (2) posição ganhou **zona de frenagem antecipada** (`POS_BRAKE_ZONE_*`: com erro < 60° e eixo em movimento, freia antes de entrar nos passos) e duty ajustado para **70%** (`POS_MAX_DUTY` — a curva real medida mostra 65% ≈ 5 RPM instável por atrito estático e 70% ≈ 400 RPM confiável): degrau 0→180° caiu de **48.6° para 4.8°** de overshoot e de 18.5 s para 3.4 s de acomodação; com ganhos agressivos (Kp=5) o overshoot caiu de 29° para ~0°; (3) Kd default do PID de velocidade 0 → **0.005** (overshoot do degrau 500→1500 RPM: 6.7% → 3.7%)
- Documentado na UI e no `AGENTS.md`: **folga mecânica da correia** — o erro residual de posição de ~1-2° é físico (backlash), não do PID; a deadband de ±2° cobre
- Senha do OTA não era aplicada (`ElegantOTA.begin` chamado sem usuário/senha corretos)
- Polaridade do encoder alinhada (horário/FORWARD = ângulo positivo) — pré-requisito do controle de posição
- Aquisição de RPM do laço de controle: janela deslizante de 80 ms + limitador de slew — elimina os picos causados por pulsos perdidos nas rajadas de Wi-Fi do ESP8266
- Malha de velocidade e auto-tune usam o módulo da velocidade (|RPM|) como realimentação — imunes à inversão de fiação; a posição continua usando o ângulo com sinal
- Auto-tune: debounce de cruzamentos (60 ms), envelope medido a partir do 2º cruzamento e período completo (entre cruzamentos pares) — Ku/Tu agora são válidos (antes Tu saía pela metade e a amplitude vinha poluída pelo transiente de partida)
- PWM de 4 kHz com 8 bits validado em bancada (motor gira normalmente, chiado do chaveamento mais discreto)
- Auto-Tune travava em motores com zona morta alta (só zumbia sem girar): relay agora alterna em torno de um pedestal `bias` (default 82%) e Ku usa a amplitude efetiva do degrau; campo Bias na UI e parâmetro `bias` na API
- Interface web travava em "conectando..." no modo AP por depender de Chart.js via CDN
- Auto-Tune: falha/timeout não deixava mais o botão travado; adicionado estado de erro e botão Parar funcional durante o experimento
- Seleção de método de sintonia (ZN/TL/CC) agora preenche os ganhos corretamente
- Capacidade de gravar a interface web (`data/`) com `pio run -t uploadfs`

## [0.1.0] - 2025-05-27

### Adicionado
- Estrutura inicial do repositório
- Firmware skeleton (PlatformIO + ESP8266)
  - Módulo de controle de motor (PWM)
  - Módulo de leitura de encoder (LPD3806-600BM)
  - Módulo OTA (ElegantOTA)
  - Interface web básica
- Templates de documentação
- Exemplos didáticos (placeholders)
- Licenças: GPL-3.0 (firmware), CERN-OHL-S-2.0 (hardware), CC-BY-SA-4.0 (docs)
- Guia de contribuição

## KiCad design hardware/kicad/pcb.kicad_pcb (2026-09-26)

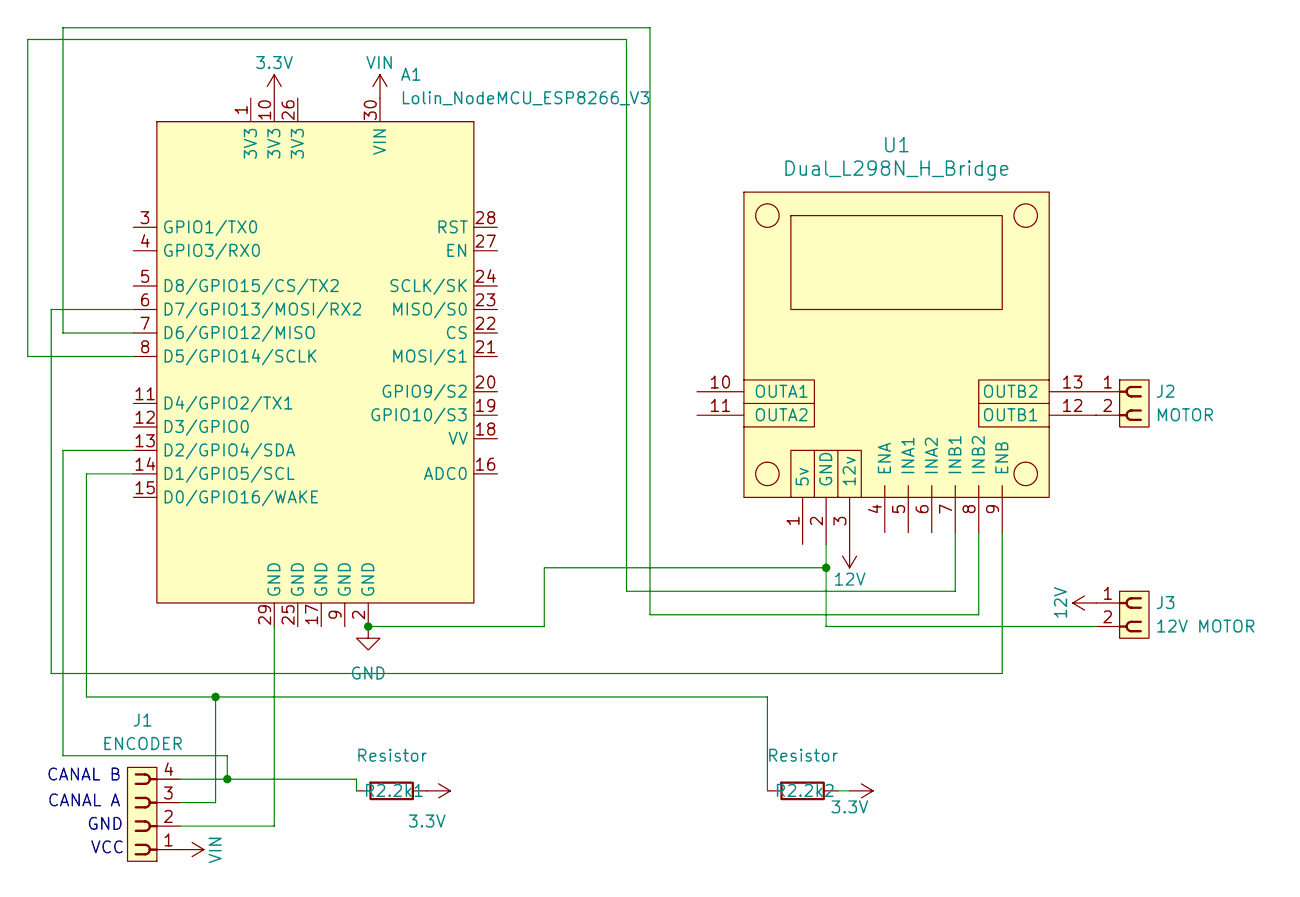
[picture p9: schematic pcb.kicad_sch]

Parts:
A1: Lolin_NodeMCU_ESP8266_V3; Lolin_NodeMCU_ESP8266
J1: ENCODER; PinSocket_1x04_P2.54mm_Vertical
J2: MOTOR; PinSocket_1x02_P2.54mm_Vertical
J3: 12V MOTOR; PinSocket_1x02_P2.54mm_Vertical
R2.2k1, R2.2k2: Resistor; R_Axial_DIN0207_L6.3mm_D2.5mm_P10.16mm_Horizontal
U1: Dual_L298N_H_Bridge

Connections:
3.3V: A1.10 (3V3), R2.2k1.2, R2.2k2.2
12V: J3.1, U1.3 (12v)
GND: A1.2 (GND), J3.2, U1.2 (GND)
unnamed: A1.14 (D1/GPIO5/SCL), J1.3, R2.2k2.1
unnamed: A1.13 (D2/GPIO4/SDA), J1.4, R2.2k1.1
unnamed: A1.8 (D5/GPIO14/SCLK), U1.7 (INB1)
unnamed: A1.7 (D6/GPIO12/MISO), U1.8 (INB2)
unnamed: A1.6 (D7/GPIO13/MOSI/RX2), U1.9 (ENB)
unnamed: A1.29 (GND), J1.2
unnamed: J2.2, U1.12 (OUTB1)
unnamed: J2.1, U1.13 (OUTB2)
VIN: A1.30 (VIN), J1.1

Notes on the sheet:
VCC
GND
CANAL B
CANAL A

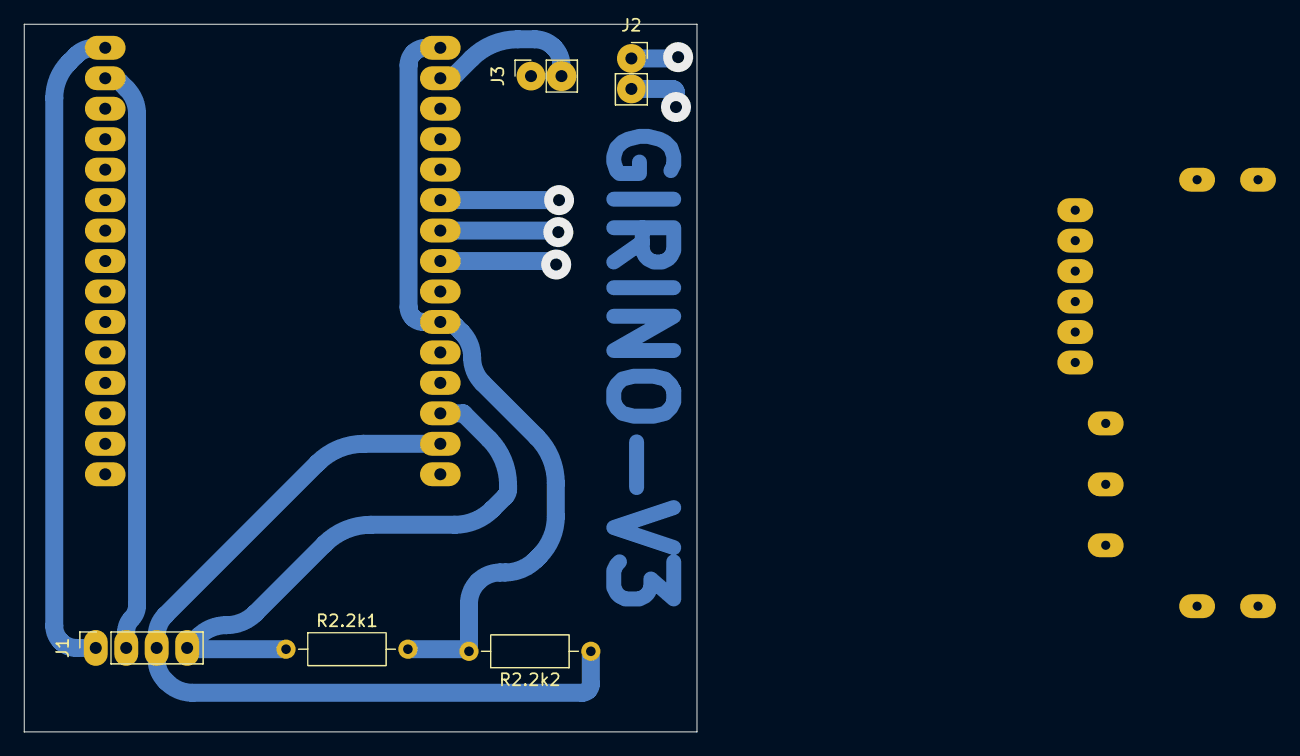
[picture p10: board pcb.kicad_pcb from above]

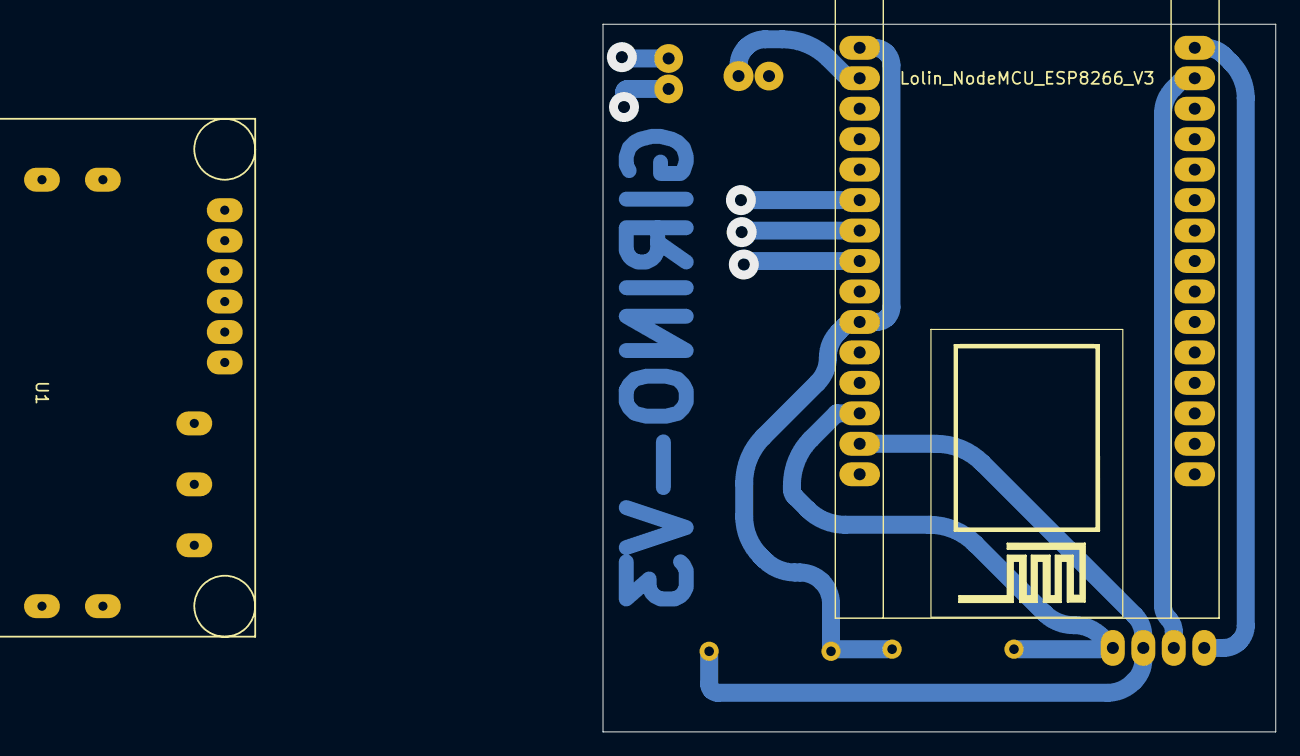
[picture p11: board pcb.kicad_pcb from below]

Board: 2 copper layers, 56.1 x 59.0 mm, 7 parts (2 on the bottom side), 12 nets.

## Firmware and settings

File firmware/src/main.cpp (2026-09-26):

/**
 * Girino — Plataforma didática de controle de motor DC
 * LaRA — Laboratório de Robótica e Automação
 *
 * Firmware principal para ESP8266 WROOM.
 * Integra controle PWM de motor, leitura de encoder incremental,
 * controle PID em malha fechada, auto-tune via relay feedback
 * e atualização OTA via Wi-Fi.
 *
 * Modos de operação (para comparação didática):
 *   - Malha aberta: PWM manual via /api/motor
 *   - Malha fechada: PID via /api/pid/...
 *   - Auto-tune: relay feedback via /api/pid/autotune
 */

#include <Arduino.h>
#include <ESP8266WiFi.h>
#include <ESP8266WebServer.h>
#include <ElegantOTA.h>
#include <LittleFS.h>

#include "pins.h"
#include "config.h"
#include "motor_control.h"
#include "encoder.h"
#include "pid.h"
#include "pid_autotune.h"
#include "pid_tuning_rules.h"
#include "serial_console.h"

// --- Web Server na porta 80 ---
ESP8266WebServer server(80);

// --- Protótipos ---
void setupWiFi();
void setupWebServer();
void handleMotorCommand();
void handleEncoderRead();
void handleStatus();
void handlePidConfig();
void handlePidStart();
void handlePidStop();
void handleAutotune();
void handlePidTuning();
void handlePidTuningApply();
void handlePidResponse();
void handlePositionConfig();
void handlePositionStart();
void handlePositionStop();
void handlePositionZero();
void controlTick(float rpm, float dt);
void recordResponse(unsigned long tMs, float rpm);
void resetResponseBuffer();
String gainsToJson(const PidGains& g);
String posConfigToJson();

// =============================================================
// BUFFER DE RESPOSTA AO DEGRAU
// =============================================================
// Amostras (t, RPM) registradas a cada tick de controle enquanto
// o PID ou o auto-tune estão ativos. Servidas via /api/pid/response.
#define RESPONSE_MAX_POINTS 512
struct ResponsePoint {
    uint16_t tMs;   // offset desde o início do experimento (ms)
    float value;    // medida do experimento (RPM ou graus, conforme unidade)
};
static ResponsePoint responseBuffer[RESPONSE_MAX_POINTS];
static int responseLen = 0;
static unsigned long responseStart = 0;
// Unidade da resposta ao degrau: "rpm" (velocidade) ou "deg" (posição)
static const char* responseUnit = "rpm";

// =============================================================
// SETUP
// =============================================================
void setup() {
    Serial.begin(BAUD_RATE);
    Serial.println();
    Serial.print("=== Girino v");
    Serial.print(FIRMWARE_VERSION);
    Serial.println(" ===");
    Serial.println("LaRA — Laboratório de Robótica e Automação");

    // Inicializar módulos
    motorControlInit();
    encoderInit();
    pidInit();
    autotuneInit();

    // Conectar Wi-Fi
    setupWiFi();

    // Inicializar filesystem
    if (!LittleFS.begin()) {
        Serial.println("[LittleFS] Falha ao montar filesystem");
    } else {
        Serial.println("[LittleFS] Filesystem montado");
    }

    // Configurar servidor web + OTA
    setupWebServer();

    // Console de comandos via serial (USB)
    serialConsoleInit();

    Serial.println("Sistema inicializado com sucesso!");
    Serial.print("Pagina de controle: http://");
    Serial.println(WiFi.softAPIP().toString());
    Serial.print("OTA: http://");
    Serial.println(WiFi.softAPIP().toString() + "/update");
}

// =============================================================
// LOOP
// =============================================================
static unsigned long lastControlTick = 0;
static long lastControlPulses = 0;

void loop() {
    server.handleClient();
    ElegantOTA.loop();
    encoderUpdate();
    encoderUpdateFeedback();  // LED + telemetria do encoder (didático)
    serialConsoleUpdate();    // comandos via serial (USB)

    // Tick de controle em tempo real (50 Hz) — PID e auto-tune
    unsigned long now = millis();
    if (now - lastControlTick >= PID_SAMPLE_MS) {
        float dt = (now - lastControlTick) / 1000.0;
        lastControlTick = now;

        long pulses = encoderGetPulses();
        long delta = pulses - lastControlPulses;
        lastControlPulses = pulses;

        // Janela deslizante (4 ticks = 80 ms): suaviza pulsos perdidos
        // nas rajadas de Wi-Fi, que gerariam picos impossíveis em 20 ms.
        static long deltaRing[CONTROL_RPM_WINDOW_TICKS] = {0};
        static float dtRing[CONTROL_RPM_WINDOW_TICKS] = {0};
        static uint8_t ringIdx = 0;
        deltaRing[ringIdx] = delta;
        dtRing[ringIdx] = dt;
        ringIdx = (ringIdx + 1) % CONTROL_RPM_WINDOW_TICKS;

        long deltaSum = 0;
        float dtSum = 0.0;
        for (int i = 0; i < CONTROL_RPM_WINDOW_TICKS; i++) {
            deltaSum += deltaRing[i];
            dtSum += dtRing[i];
        }
        float rpmRaw = (dtSum > 0.0)
                           ? ((float)deltaSum / (float)ENCODER_PPR) * (60.0 / dtSum)
                           : 0.0;

        // Limitador de slew: o motor não varia mais que CONTROL_RPM_SLEW_MAX
        // por segundo — saltos maiores são ruído de medição e são aparados.
        static float rpmCtrl = 0.0;
        float maxStep = CONTROL_RPM_SLEW_MAX * dt;
        if (rpmRaw > rpmCtrl + maxStep) rpmRaw = rpmCtrl + maxStep;
        if (rpmRaw < rpmCtrl - maxStep) rpmRaw = rpmCtrl - maxStep;
        rpmCtrl = rpmRaw;

        controlTick(rpmCtrl, dt);
    }
}

/**
 * Tick de controle: decide quem aciona o motor.
 * Prioridade: auto-tune > posição > velocidade (PID) > malha aberta.
 */
void controlTick(float rpm, float dt) {
    // Telemetria didática (2x/s) enquanto um controlador está ativo —
    // permite acompanhar o experimento pelo monitor serial.
    static unsigned long lastTelemetry = 0;
    unsigned long nowMs = millis();
    bool verbose = (nowMs - lastTelemetry >= 500);
    if (verbose) lastTelemetry = nowMs;

    if (autotuneIsRunning()) {
        if (autotuneGetPlant() == AUTOTUNE_PLANT_POSITION) {
            // Relay bidirecional na malha de posição: oscila em torno do
            // alvo em graus. Saída com sinal define o sentido de giro.
            float angle = encoderGetAngle();
            autotuneCompute(angle, dt);
            float out = autotuneGetRelayOutput();
            if (out >= 0.0) {
                motorSetDirection(MOTOR_DIR_FORWARD);
                motorSetSpeed((int)out);
            } else {
                motorSetDirection(MOTOR_DIR_REVERSE);
                motorSetSpeed((int)(-out));
            }
            recordResponse(millis() - responseStart, angle);
            if (verbose) Serial.printf("[AutoTune] Alvo=%.1f Angulo=%.1f relay=%.0f%%\n",
                                       posGetTarget(), angle, out);
        } else {
            // Relay unidirecional na malha de velocidade: usa o módulo da
            // velocidade para ficar imune à inversão de fiação motor/encoder.
            float rpmAbs = fabs(rpm);
            autotuneCompute(rpmAbs, dt);
            float out = autotuneGetRelayOutput();
            motorSetDirection(MOTOR_DIR_FORWARD);
            motorSetSpeed((int)out);
            recordResponse(millis() - responseStart, rpmAbs);
            if (verbose) Serial.printf("[AutoTune] RPM=%.0f relay=%.0f%%\n", rpmAbs, out);
        }

        // Experimento terminou?
        if (autotuneIsDone() || autotuneIsFailed()) {
            motorSetSpeed(0);
            motorSetDirection(MOTOR_DIR_STOP);
        }
    } else if (posIsRunning()) {
        // Malha de posição — atuação em camadas (bang-bang com passos):
        //   1. deadband (±2°), ou o PID pedindo repouso -> FREIO dinâmico;
        //   2. perto do alvo (< 30°): PASSOS discretos — KICK ticks de
        //      chute + REST ticks de freio; direção pelo SINAL DO ERRO;
        //   3. longe: duty fixo POS_MAX_DUTY (65%) — NUNCA 100%: o soco
        //      com ciclos de freio a 50 Hz levou o L298N ao desligamento
        //      térmico na bancada (eixo travou a 171° além do alvo).
        static int softPhase = 0;
        float angle = encoderGetAngle();
        float error = posGetTarget() - angle;
        float out = posCompute(angle, dt);
        float rpmAbs = fabsf(rpm);

        if (fabsf(error) <= POS_DEADBAND_DEG || fabsf(out) < POS_DRIVE_EPS) {
            motorBrake();
            softPhase = 0;
        } else if (fabsf(error) < POS_BRAKE_ZONE_DEG && rpmAbs > POS_BRAKE_ZONE_RPM) {
            // Frenagem antecipada: ainda longe do alvo mas em movimento —
            // freia ANTES de entrar na zona de passos, senão a velocidade
            // de entrada atravessa o alvo (overshoot).
            motorBrake();
            softPhase = 0;
        } else if (fabsf(error) < POS_SOFT_NEAR_DEG) {
            if (softPhase < POS_SOFT_KICK_TICKS) {
                if (error > 0) {
                    motorSetDirection(MOTOR_DIR_FORWARD);
                    motorSetSpeed(POS_MAX_DUTY);
                } else {
                    motorSetDirection(MOTOR_DIR_REVERSE);
                    motorSetSpeed(POS_MAX_DUTY);
                }
                softPhase++;
            } else if (softPhase < POS_SOFT_KICK_TICKS + POS_SOFT_REST_TICKS) {
                motorBrake();
                softPhase++;
            } else {
                softPhase = 0;
            }
        } else {
            softPhase = 0;
            // Direção pela saída do PID (sinal), duty na região confiável
            if (out >= 0.0) {
                motorSetDirection(MOTOR_DIR_FORWARD);
                motorSetSpeed(POS_MAX_DUTY);
            } else {
                motorSetDirection(MOTOR_DIR_REVERSE);
                motorSetSpeed(POS_MAX_DUTY);
            }
        }
        recordResponse(millis() - responseStart, angle);
        if (verbose) Serial.printf("[Pos] Alvo=%.1f Angulo=%.1f Out=%.0f%%\n", posGetTarget(), angle, out);
    } else if (pidIsRunning()) {
        // A malha de velocidade é unidirecional (só horário): usa o módulo
        // da velocidade como realimentação — assim continua regulando mesmo
        // se a fiação do motor/encoder estiver invertida.
        float rpmAbs = fabs(rpm);
        float out = pidCompute(rpmAbs, dt);
        motorSetDirection(MOTOR_DIR_FORWARD);
        motorSetSpeed((int)out);
        recordResponse(millis() - responseStart, rpmAbs);
        if (verbose) Serial.printf("[PID] SP=%.0f RPM=%.0f Out=%.0f%%\n", pidGetSetpoint(), rpmAbs, out);

        // Aviso didático: giro no sentido oposto ao esperado pela fiação.
        static bool polarityWarned = false;
        if (rpm < -50.0 && !polarityWarned) {
            polarityWarned = true;
            Serial.println("[PID] Aviso: motor gira ao contrario da fiacao esperada — verifique motor/encoder");
        }
    }
    // Sem PID nem auto-tune: motor segue o último comando manual
    // (tratado em handleMotorCommand) — malha aberta para comparação.
}

// =============================================================
// BUFFER DE RESPOSTA
// =============================================================
void resetResponseBuffer() {
    responseLen = 0;
    responseStart = millis();
}

/**
 * Define a unidade da resposta ao degrau ("rpm" ou "deg").
 * Usado pelos controladores (web e console serial).
 */
void setResponseUnit(const char* unit) {
    responseUnit = unit;
}

void recordResponse(unsigned long tMs, float value) {
    if (responseLen >= RESPONSE_MAX_POINTS) return;
    responseBuffer[responseLen].tMs = (uint16_t)tMs;
    responseBuffer[responseLen].value = value;
    responseLen++;
}

// =============================================================
// Implementações — Wi-Fi e servidor
// =============================================================

void setupWiFi() {
    // Modo Access Point: o Girino cria sua própria rede Wi-Fi.
    // Vantagem didática: alunos conectam direto pelo celular ou
    // notebook, sem depender de roteador, internet ou credenciais
    // de rede externa. O IP fixo 192.168.4.1 é o endereço da página.
    WiFi.mode(WIFI_AP);

    // IMPORTANTE: configurar o IP ANTES de subir o AP. Se chamado
    // depois, o servidor DHCP embutido não reinicia e os clientes
    // conectam sem receber endereço IP.
    IPAddress ip = AP_LOCAL_IP;
    WiFi.softAPConfig(ip, ip, IPAddress(255, 255, 255, 0));

    // Senha do AP precisa ter >= 8 caracteres; caso contrário,
    // sobe uma rede aberta (sem senha) para não bloquear a aula.
    const char* apPass = WIFI_PASSWORD;
    bool apOpen = (strlen(apPass) < 8);
    bool ok;
    if (apOpen) {
        ok = WiFi.softAP(WIFI_SSID);
        Serial.println("[WiFi] Senha do AP curta (<8 chars) — rede aberta!");
    } else {
        ok = WiFi.softAP(WIFI_SSID, apPass);
    }

    if (ok) {
        Serial.printf("[WiFi] Access Point '%s' ativo\n", WIFI_SSID);
        Serial.printf("[WiFi] IP: %s\n", WiFi.softAPIP().toString().c_str());
    } else {
        Serial.println("[WiFi] Falha ao criar Access Point!");
    }
}

void setupWebServer() {
    // Arquivos estáticos do LittleFS
    server.serveStatic("/style.css", LittleFS, "/style.css");
    server.serveStatic("/app.js", LittleFS, "/app.js");
    // Chart.js local — o modo AP não tem internet, então a lib não
    // pode vir de CDN; ela é servida do próprio LittleFS.
    server.serveStatic("/chart.umd.min.js", LittleFS, "/chart.umd.min.js");

    // Página principal — servir index.html do LittleFS
    server.on("/", HTTP_GET, []() {
        File file = LittleFS.open("/index.html", "r");
        if (file) {
            server.streamFile(file, "text/html");
            file.close();
        } else {
            server.send(404, "text/plain", "index.html nao encontrado no LittleFS");
        }
    });

    // API: Comando do motor (malha aberta)
    server.on("/api/motor", HTTP_POST, handleMotorCommand);

    // API: Leitura do encoder
    server.on("/api/encoder", HTTP_GET, handleEncoderRead);

    // API: Status do sistema
    server.on("/api/status", HTTP_GET, handleStatus);

    // API: PID
    server.on("/api/pid/config", HTTP_GET, handlePidConfig);
    server.on("/api/pid/config", HTTP_POST, handlePidConfig);
    server.on("/api/pid/start", HTTP_POST, handlePidStart);
    server.on("/api/pid/stop", HTTP_POST, handlePidStop);
    server.on("/api/pid/response", HTTP_GET, handlePidResponse);

    // API: Auto-tune (relay feedback) e regras de sintonia
    server.on("/api/pid/autotune", HTTP_GET, handleAutotune);
    server.on("/api/pid/autotune", HTTP_POST, handleAutotune);
    server.on("/api/pid/tuning", HTTP_GET, handlePidTuning);
    server.on("/api/pid/tuning/apply", HTTP_POST, handlePidTuningApply);

    // API: Controle de posição (ângulo)
    server.on("/api/position/config", HTTP_GET, handlePositionConfig);
    server.on("/api/position/config", HTTP_POST, handlePositionConfig);
    server.on("/api/position/start", HTTP_POST, handlePositionStart);
    server.on("/api/position/stop", HTTP_POST, handlePositionStop);
    server.on("/api/position/zero", HTTP_POST, handlePositionZero);

    // OTA com senha
    ElegantOTA.begin(&server, "admin", OTA_PASSWORD);
    ElegantOTA.setAutoReboot(true);

    server.begin();
    Serial.println("Servidor HTTP + OTA iniciado");
}

// =============================================================
// Handlers — malha aberta, encoder e status
// =============================================================

void handleMotorCommand() {
    if (!server.hasArg("direction") || !server.hasArg("speed")) {
        server.send(400, "application/json", "{\"error\":\"missing parameters\"}");
        return;
    }

    // Comando manual desliga PID, auto-tune e posição (modo comparação)
    pidStop();
    autotuneCancel();
    posStop();

    String direction = server.arg("direction");
    int speed = server.arg("speed").toInt();

    if (direction == "forward") {
        motorSetDirection(MOTOR_DIR_FORWARD);
        motorSetSpeed(speed);
    } else if (direction == "reverse") {
        motorSetDirection(MOTOR_DIR_REVERSE);
        motorSetSpeed(speed);
    } else if (direction == "stop") {
        motorSetSpeed(0);
    } else {
        server.send(400, "application/json", "{\"error\":\"invalid direction\"}");
        return;
    }

    String json = "{\"direction\":\"" + direction + "\",\"speed\":" + String(speed) + "}";
    server.send(200, "application/json", json);
}

void handleEncoderRead() {
    long pulses = encoderGetPulses();
    float rpm = encoderGetRPM();
    float angle = encoderGetAngle();

    String json = "{\"pulses\":" + String(pulses) + ",\"rpm\":" + String(rpm, 1) +
                  ",\"angle\":" + String(angle, 1) + "}";
    server.send(200, "application/json", json);
}

void handleStatus() {
    String json = "{";
    json += "\"version\":\"" FIRMWARE_VERSION "\",";
    json += "\"wifi_rssi\":" + String(WiFi.RSSI()) + ",";
    json += "\"stations\":" + String(WiFi.softAPgetStationNum()) + ",";
    json += "\"ssid\":\"" + String(WIFI_SSID) + "\",";
    json += "\"ip\":\"" + WiFi.softAPIP().toString() + "\",";
    json += "\"uptime_ms\":" + String(millis()) + ",";
    json += "\"free_heap\":" + String(ESP.getFreeHeap()) + ",";
    json += "\"angle\":" + String(encoderGetAngle(), 1) + ",";
    json += "\"mode\":\"";
    if (autotuneIsRunning()) json += "autotune";
    else if (posIsRunning()) json += "position";
    else if (pidIsRunning()) json += "pid";
    else json += "open-loop";
    json += "\"";
    json += "}";
    server.send(200, "application/json", json);
}

// =============================================================
// Handlers — PID
// =============================================================

String pidConfigToJson() {
    String json = "{";
    json += "\"kp\":" + String(pidGetKp(), 4) + ",";
    json += "\"ki\":" + String(pidGetKi(), 4) + ",";
    json += "\"kd\":" + String(pidGetKd(), 4) + ",";
    json += "\"setpoint\":" + String(pidGetSetpoint(), 1) + ",";
    json += "\"running\":" + String(pidIsRunning() ? "true" : "false") + ",";
    // Leitura ao vivo para a interface (didático): medida, erro e saída
    json += "\"measurement\":" + String(pidIsRunning() ? fabs(encoderGetRPM()) : 0.0f, 1) + ",";
    json += "\"error\":" + String(pidIsRunning() ? pidGetSetpoint() - fabs(encoderGetRPM()) : 0.0f, 1) + ",";
    json += "\"output\":" + String(pidGetOutput(), 1) + ",";
    json += "\"mode\":\"";
    json += pidIsRunning() ? "pid" : "open-loop";
    json += "\"";
    json += "}";
    return json;
}

void handlePidConfig() {
    if (server.method() == HTTP_GET) {
        server.send(200, "application/json", pidConfigToJson());
        return;
    }

    // POST: configura ganhos e setpoint (setpoint em RPM)
    if (!server.hasArg("kp") || !server.hasArg("ki") || !server.hasArg("kd")) {
        server.send(400, "application/json", "{\"error\":\"missing gains\"}");
        return;
    }

    float kp = server.arg("kp").toFloat();
    float ki = server.arg("ki").toFloat();
    float kd = server.arg("kd").toFloat();
    float setpoint = server.hasArg("setpoint") ? server.arg("setpoint").toFloat()
                                               : pidGetSetpoint();

    if (setpoint < 0.0 || setpoint > PID_MAX_SETPOINT) {
        server.send(400, "application/json", "{\"error\":\"invalid setpoint\"}");
        return;
    }

    pidConfigure(kp, ki, kd, setpoint);
    server.send(200, "application/json", pidConfigToJson());
}

void handlePidStart() {
    motorSetDirection(MOTOR_DIR_FORWARD);
    posStop();               // posição e velocidade não rodam juntos
    autotuneCancel();
    responseUnit = "rpm";
    resetResponseBuffer();
    pidStart();
    server.send(200, "application/json", "{\"ok\":true,\"mode\":\"pid\"}");
}

void handlePidStop() {
    pidStop();
    motorSetSpeed(0);
    motorSetDirection(MOTOR_DIR_STOP);
    server.send(200, "application/json", "{\"ok\":true,\"mode\":\"open-loop\"}");
}

void handlePidResponse() {
    // Em modo posição o alvo é o ângulo; em velocidade, o RPM.
    float sp = (strcmp(responseUnit, "deg") == 0) ? posGetTarget()
                                                  : pidGetSetpoint();

    String json = "{\"data\":[";
    for (int i = 0; i < responseLen; i++) {
        if (i > 0) json += ",";
        float t = (float)responseBuffer[i].tMs / 1000.0;
        json += "[" + String(t, 3) + "," +
                String(sp, 1) + "," +
                String(responseBuffer[i].value, 1) + "]";
    }
    json += "],\"setpoint\":" + String(sp, 1);
    json += ",\"unit\":\"" + String(responseUnit) + "\"";
    json += "}";
    server.send(200, "application/json", json);
}

// =============================================================
// Handlers — Auto-tune (relay feedback)
// =============================================================
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

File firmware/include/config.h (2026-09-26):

/**
 * config.h — Constantes e configurações do firmware Girino
 */

#ifndef CONFIG_H
#define CONFIG_H

#include "pins.h"

// --- Versão do firmware ---
#define FIRMWARE_VERSION "0.1.0"

// --- Serial ---
#ifndef BAUD_RATE
#define BAUD_RATE 115200
#endif

// --- Wi-Fi (Access Point) ---
// O Girino opera como Access Point: cria sua própria rede para que
// os alunos conectem direto pelo navegador, sem roteador nem internet.
// Credenciais sobrescritáveis via build_flags (.env).
// IMPORTANTE: a senha do AP precisa ter no mínimo 8 caracteres.
#ifndef WIFI_SSID
#define WIFI_SSID "GIRINO_AP"
#endif

#ifndef WIFI_PASSWORD
#define WIFI_PASSWORD "girino123"
#endif

#ifndef OTA_PASSWORD
#define OTA_PASSWORD "girino"
#endif

// IP fixo do Girino na rede do AP (gateway para os clientes conectados)
#define AP_LOCAL_IP IPAddress(192, 168, 4, 1)

// --- Motor ---
// PWM por software do ESP8266: o core limita frequência x passos a ~1 MHz.
// 4 kHz x 255 passos (8-bit) deixa o chiado do chaveamento mais discreto
// e mantém 0,4% de resolução de duty.
// Bancada medida: zona morta ~60%, 100% -> ~1950 RPM (10 V no motor).
#define MOTOR_PWM_FREQ     4000    // Frequência PWM em Hz
#define MOTOR_PWM_RANGE    255     // Resolução PWM (8-bit)
#define MOTOR_MAX_SPEED    100     // Velocidade máxima em %

// --- Pulso de calibração do sentido da fiação ---
// Pulso curto no primeiro movimento após o boot para descobrir o sentido
// físico motor/encoder. Curva real medida na bancada: zona morta ~65%,
// joelho íngreme (70% -> ~400 RPM) — não dá para calibrar devagar sem o
// atrito estático travar. Estratégia: pulso de 70% por 50 ms (giro
// ~45-60°, ~80+ pulsos — limiar: 30) SEGUIDO DE FREIO, que mata a
// inércia (antes, roda-livre + 100%/150 ms girava 400°+ = mais de uma
// volta, parecia overshoot no gráfico logo ao iniciar).
#define MOTOR_CALIB_DUTY     70
#define MOTOR_CALIB_MS       50
#define MOTOR_CALIB_BRAKE_MS 40

// --- Encoder LPD3806-600BM ---
#define ENCODER_PPR        600     // Pulsos por revolução
#define ENCODER_SAMPLE_MS  100     // Intervalo de amostragem para cálculo de RPM

// --- Feedback do encoder (didático) ---
// O LED onboard pisca a cada pulso recebido — dá para conferir a
// fiação/leitura do encoder sem abrir o navegador.
#define ENCODER_LED_ACTIVITY_MS   60     // Tempo que o LED fica aceso (ms)
#define ENCODER_DEBUG_INTERVAL_MS 1000   // Telemetria no serial (ms); 0 desativa

// --- Direções do motor ---
#define MOTOR_DIR_FORWARD   1
#define MOTOR_DIR_REVERSE  -1
#define MOTOR_DIR_STOP      0    // roda-livre (L298N: IN3=IN4=LOW, EN=0)
#define MOTOR_DIR_BRAKE     2    // freio dinâmico (L298N: IN3=IN4=HIGH)

// --- PID / Auto-Tune ---
#define PID_SAMPLE_MS       20      // Período de amostragem do PID (50 Hz)
#define PID_OUTPUT_MAX      100.0   // Saída máxima do PID (% PWM)
#define PID_OUTPUT_MIN      0.0     // Saída mínima do PID (% PWM)
#define PID_MAX_SETPOINT    3000.0  // Limite de setpoint de velocidade (RPM)
#define PID_MAX_PPR_WINDOW  20.0    // Janela de leitura do encoder (ms) p/ RPM do PID

// --- Aquisição de velocidade no laço de controle ---
// O Wi-Fi do ESP8266 bloqueia interrupções em rajadas, então contagens
// de 20 ms podem perder pulsos e "pular". A janela deslizante e o
// limitador de slew rejeitam essas leituras impossíveis.
#define CONTROL_RPM_WINDOW_TICKS 4      // janela deslizante (4 x 20 ms = 80 ms)
#define CONTROL_RPM_SLEW_MAX     8000.0 // aceleração máxima plausível (RPM/s)
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

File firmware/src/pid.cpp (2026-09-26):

/**
 * pid.cpp — Núcleo PID compartilhado (velocidade e posição)
 *
 * Educational notes (for the students):
 *
 * The controller uses the standard positional form, discretized:
 *
 *   u[k] = Kp * e[k] + Ki * integral(e) + Kd * derivative
 *
 * Two practical details matter for real motors:
 *
 * 1. ANTI-WINDUP: when the motor saturates (e.g. 100% PWM during a big
 *    step), the integral term would keep growing ("windup") and cause a
 *    huge overshoot when the setpoint is finally reached. We handle it
 *    two ways: (a) conditional integration — the integral is frozen while
 *    the output is saturated in the same direction of the error — and
 *    (b) a hard clamp on the integral as a last resort.
 *
 * 2. DERIVATIVE ON MEASUREMENT: differentiating the error causes a
 *    "derivative kick" every time the setpoint changes. Differentiating
 *    the measurement instead (with a negative sign) gives the same
 *    regulation effect without the kick.
 *
 * O mesmo núcleo é usado por dois controladores:
 *   - velocidade: saída 0..+100% (somente horário)
 *   - posição:    saída -100..+100% (bidirecional)
 */

#include <Arduino.h>
#include "pid.h"
#include "motor_control.h"

// --- Núcleo genérico de um controlador PID ---
struct PidCore {
    PidState state;
    float kp, ki, kd;
    float setpoint;
    float integral;
    float prevMeasurement;
    float output;
    float outMin, outMax;
    float integralTermMax;     // teto da contribuição integral (% de saída)
    float derivativeTermMax;   // teto da contribuição derivativa (% de saída)
    bool firstSample;  // primeiro passo após start: sem derivada
};

static PidCore speedPid;
static PidCore posPid;

static void coreInit(PidCore& c, float outMin, float outMax) {
    c.state = PID_IDLE;
    c.kp = c.ki = c.kd = 0.0;
    c.setpoint = 0.0;
    c.integral = 0.0;
    c.prevMeasurement = 0.0;
    c.output = 0.0;
    c.outMin = outMin;
    c.outMax = outMax;
    c.integralTermMax = outMax;        // por padrão, sem teto extra
    c.derivativeTermMax = outMax;      // por padrão, sem teto do D
    c.firstSample = true;
}

static void coreReset(PidCore& c) {
    c.integral = 0.0;
    c.prevMeasurement = 0.0;
    c.output = 0.0;
    c.firstSample = true;
}

static float coreCompute(PidCore& c, float measurement, float dt) {
    if (dt <= 0.0) return c.output;

    // No primeiro passo após o start, memoriza a medição atual para
    // que a derivada não dê um "salto" (0 -> medição real).
    if (c.firstSample) {
        c.prevMeasurement = measurement;
        c.firstSample = false;
    }

    float error = c.setpoint - measurement;

    // --- Integral with anti-windup ---
    float newIntegral = c.integral + error * dt;

    // --- Derivative on measurement ---
    // Teto da CONTRIBUIÇÃO derivativa (em % de saída, não no de/dt cru):
    // com o eixo a toda velocidade o de/dt passa de 10.000 °/s e o termo
    // D sozinho inverteria a saída a cada tick. O clamp mantém o
    // amortecimento sem o soco.
    float derivative = -(measurement - c.prevMeasurement) / dt;
    float dTerm = c.kd * derivative;
    if (c.derivativeTermMax < c.outMax) {
        dTerm = fmaxf(-c.derivativeTermMax,
                      fminf(c.derivativeTermMax, dTerm));
    }

    // --- Raw output ---
    float rawOutput = c.kp * error + c.ki * newIntegral + dTerm;

    // --- Saturation / anti-windup (conditional integration) ---
    bool saturatedHigh = rawOutput > c.outMax;
    bool saturatedLow  = rawOutput < c.outMin;
    bool pushingHigh   = error > 0.0;
    bool pushingLow    = error < 0.0;

    if ((saturatedHigh && pushingHigh) || (saturatedLow && pushingLow)) {
        // Do not integrate while pushing further into saturation
        newIntegral = c.integral;
        rawOutput = c.kp * error + c.ki * newIntegral + dTerm;
    }

    // Hard clamp on the integral as a last resort.
    // O teto da CONTRIBUIÇÃO integral (integralTermMax, em % de saída)
    // limita o que o termo Ki*I consegue sozinho — na malha de posição,
    // manter o termo integral abaixo da zona morta do motor evita que o
    // motor fique acionado para sempre com erro ~0 (rastejo além do alvo).
    float integralMin = c.outMin / (c.ki > 0.0 ? c.ki : 1.0);
    float integralMax = c.outMax / (c.ki > 0.0 ? c.ki : 1.0);
    if (c.integralTermMax < c.outMax) {
        integralMax = fminf(integralMax, c.integralTermMax / (c.ki > 0.0 ? c.ki : 1.0));
        integralMin = fmaxf(integralMin, -integralMax);
    }
    if (newIntegral > integralMax) newIntegral = integralMax;
    if (newIntegral < integralMin) newIntegral = integralMin;

    c.integral = newIntegral;
    c.prevMeasurement = measurement;

    // Final clamp
    if (rawOutput > c.outMax) rawOutput = c.outMax;
    if (rawOutput < c.outMin) rawOutput = c.outMin;
    c.output = rawOutput;

    return c.output;
}

void pidInit() {
    coreInit(speedPid, PID_OUTPUT_MIN, PID_OUTPUT_MAX);
    coreInit(posPid, POS_OUTPUT_MIN, POS_OUTPUT_MAX);
    posPid.integralTermMax = POS_INTEGRAL_TERM_MAX;      // abaixo da zona morta do motor
    posPid.derivativeTermMax = POS_DERIVATIVE_TERM_MAX;  // sem soco do D em alta velocidade
    Serial.println("[PID] Inicializado");
    Serial.println("[Pos] Controle de posicao inicializado (angulo)");
}

// =============================================================
// PID de velocidade
// =============================================================

void pidConfigure(float kp, float ki, float kd, float setpoint) {
    speedPid.kp = kp;
    speedPid.ki = ki;
    speedPid.kd = kd;
    speedPid.setpoint = setpoint;

    coreReset(speedPid);

    Serial.print("[PID] Config: Kp=");
    Serial.print(kp);
    Serial.print(" Ki=");
    Serial.print(ki);
    Serial.print(" Kd=");
    Serial.print(kd);
    Serial.print(" SP=");
    Serial.println(setpoint);
}

void pidStart() {
    coreReset(speedPid);
    speedPid.state = PID_RUNNING;
    Serial.println("[PID] Controle em malha fechada iniciado");
}

void pidStop() {
    speedPid.state = PID_IDLE;
    coreReset(speedPid);
    Serial.println("[PID] Controle parado");
}

bool pidIsRunning() {
    return speedPid.state == PID_RUNNING;
}

float pidCompute(float measurement, float dt) {
    if (speedPid.state != PID_RUNNING) return 0.0;
    return coreCompute(speedPid, measurement, dt);
}

float pidGetKp() { return speedPid.kp; }
float pidGetKi() { return speedPid.ki; }
float pidGetKd() { return speedPid.kd; }
float pidGetSetpoint() { return speedPid.setpoint; }
float pidGetOutput() { return speedPid.output; }

// =============================================================
// PID de posição (ângulo)
// =============================================================
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

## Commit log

2026-05-27 docs: adicionar AGENTS.md com contexto para agentes de IA
2026-05-27 docs: adicionar levantamento bibliográfico com ~55 referências para artigo
    - docs/referencias-pesquisa.md: referências organizadas por relevância
    - Tier 1: trabalhos diretamente relacionados (motor DC + encoder + PID + educação)
    - Plataformas open-source: MotoShield, AutomationShield, OpenMCT, TCLab
    - Publicações brasileiras: CBA, SBAI, COBENGE
    - ESP8266/ESP32 para ensino de controle
    - Simulação vs hardware real
    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
2026-05-27 docs: adicionar análise comparativa e referências RBEF
    - docs/analise-comparativa.md: review de 7 trabalhos relacionados (Cabral
    2025, Alexandre 2025, Segundo 2019, MotoShield, OpenMCT, Reck 2015,
    TCLab), tabela comparativa geral, gap analysis, argumentação para artigo,
    estratégia de publicação
    - docs/referencias-pesquisa.md: +15 referências (13 papers RBEF + 2 revisões
    sistemáticas brasileiras), seção de veículos recomendados
    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

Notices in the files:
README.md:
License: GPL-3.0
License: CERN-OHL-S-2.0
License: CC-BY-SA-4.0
